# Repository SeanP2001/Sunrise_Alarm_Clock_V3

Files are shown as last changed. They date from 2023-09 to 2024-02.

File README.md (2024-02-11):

# Sunrise Alarm Clock V3

**Table of Contents**

- [Introduction](#introduction)
- [Brief](#brief)
- [Development Roadmap](#development-roadmap)
- [Circuitry](#circuitry)
  - [Schematics](#schematics)
    - [Main PCB](#main-pcb)
    - [Button PCB](#button-pcb)
    - [Light PCB](#light-pcb)
  - [PCB Design](#pcb-design)
    - [Main PCB](#main-pcb-1)
    - [Button PCB](#button-pcb-1)
    - [Light PCB](#light-pcb-1)
  - [Soldering](#soldering)
    - [Main PCB](#main-pcb-2)
    - [Button PCB](#button-pcb-2)
    - [Light PCB](#light-pcb-2)
- [Enclosure](#enclosure)
  - [CAD Enclosure](#cad-enclosure)
  - [Assembled Enclosure](#assembled-enclosure)
- [Code](#code)
  - [Documentation](#documentation)
  - [How to Add a New App](#how-to-add-a-new-app)
- [Further Work](#further-work)

## Introduction

This is the third version of the "Sunrise Alarm Clock" project. [The first version](https://github.com/SeanP2001/Arduino_Sunrise_Alarm_Clock) used an Arduino Mega and an LCD keypad shield. [The second version](https://github.com/SeanP2001/Sunrise_Alarm_Clock_V2) used a Wemos D1 mini (ESP8266) and 0.96" OLED on a single custom PCB. This design was fully functional but it did not look like an alarm clock. I started version 3 with the aim of making the alarm look more premium. 

<div style="display: flex; justify-content: space-between;">
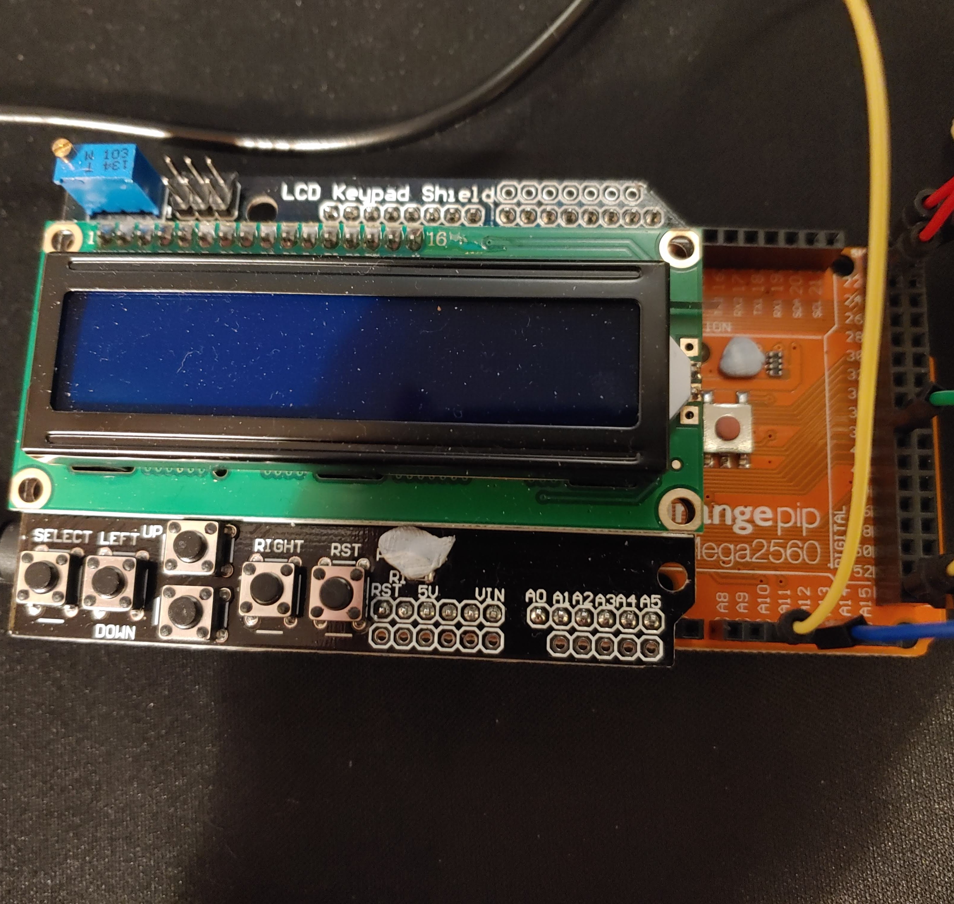
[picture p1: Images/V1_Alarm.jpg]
Alarm V1
    
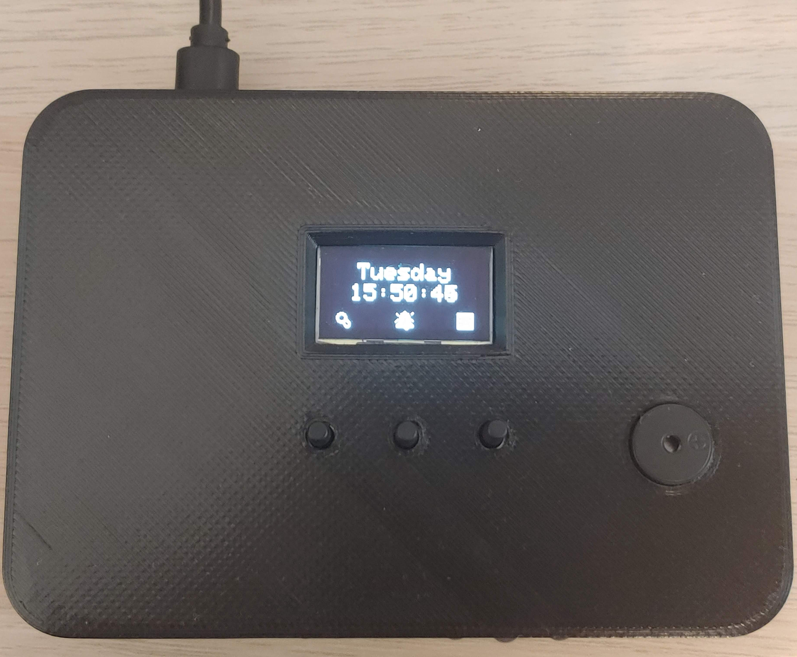
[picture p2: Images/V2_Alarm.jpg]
Alarm V2
    
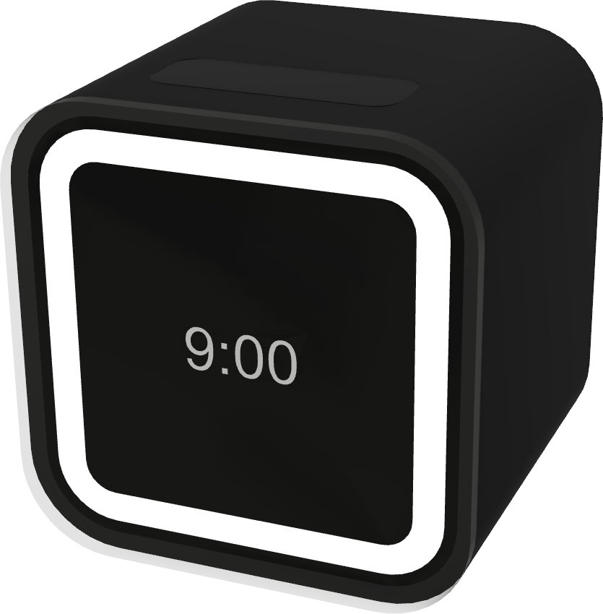
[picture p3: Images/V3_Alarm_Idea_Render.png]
Alarm V3 Concept
    
</div>
<p align="center"><i>Alarm V1, Alarm V2 and Alarm V3 Concept</i></p>

This project was sponsored by PCBWay. To order high-quality, custom PCBs go to [PCBWay.com](https://www.pcbway.com/)

## Brief

The alarm needed to:
- Tell the time
- Use a real-time clock (RTC) to keep the time 
- Use an NTP server to update the time periodically
- Include a larger, 1.5" OLED 
- Include three capacitive touch buttons
- Include two timed USB ports
- Include a bright ringlight on the clock face
- Include a buzzer
- Have a premium feel

## Development Roadmap

The following roadmap outlines the planned milestones for the project. Each step includes testing and documenting.

| **Version** | **Description** |
|---|---|
| V3.1-alpha | Capture Schematic |
| V3.2-alpha | Design Main PCB |
| V3.3-alpha | Design Light PCB |
| V3.4-alpha | Design Button PCB |
| V3.5-alpha | Design and Fabricate Enclosure |
| V3.6-alpha | Solder and Assemble |
| V3.7-alpha | Test Hardware and Document |
| V3.8-alpha | Program Inputs and Outputs |
| V3.9-alpha | Implement App Infrastructure |
| V3.10-alpha | Develop Alarm App |
| V3.11-alpha | Develop Light App |
| V3.12-alpha | Develop USB App |
| V3.13-alpha | Develop Settings App |
| V3.14-alpha | Implement WiFi, NTP Time Sync and Settings Portal |
| V3.0-release  | Initial Release (Document, Test and Fix Bugs) |

## Circuitry

### Schematics

#### Main PCB

<p align="center">
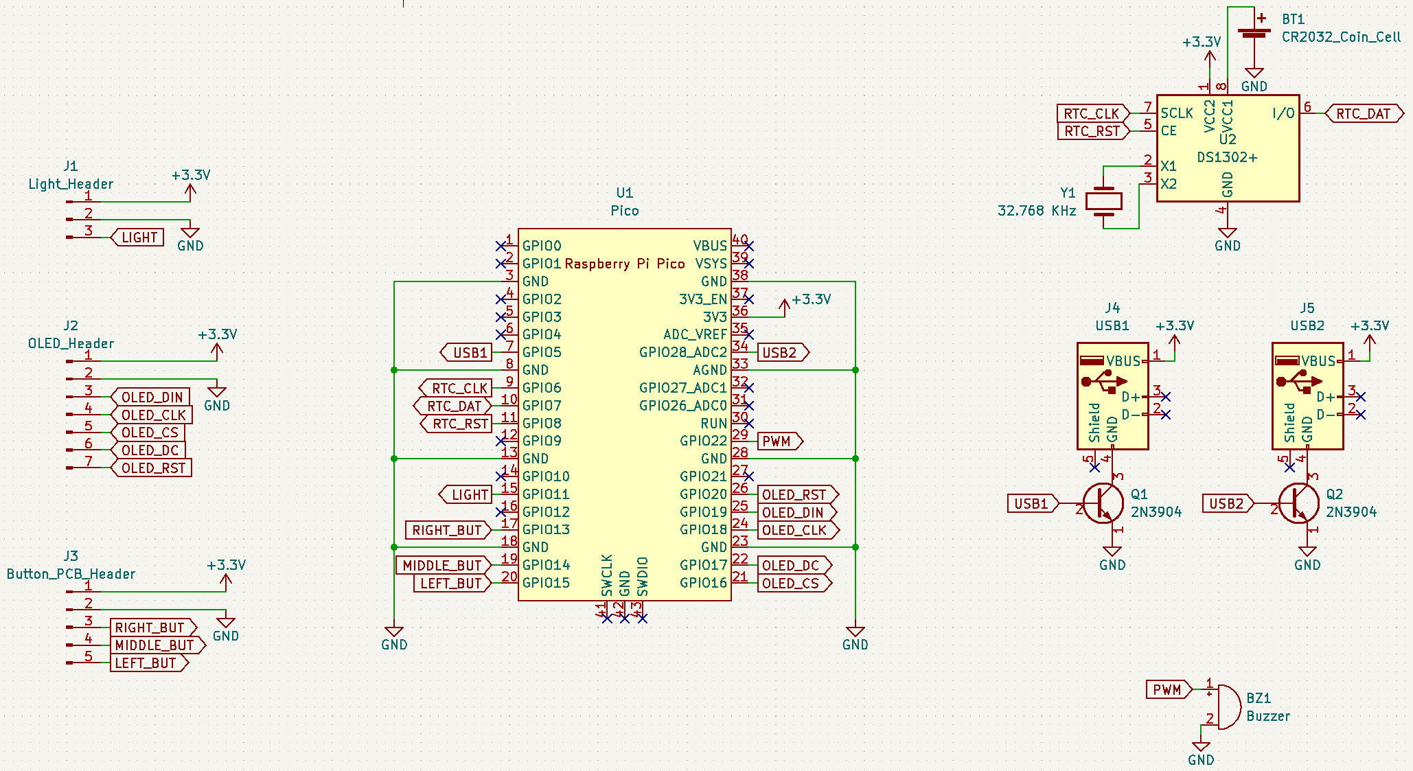
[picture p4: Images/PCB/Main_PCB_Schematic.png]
  
</p>

#### Button PCB

<p align="center">
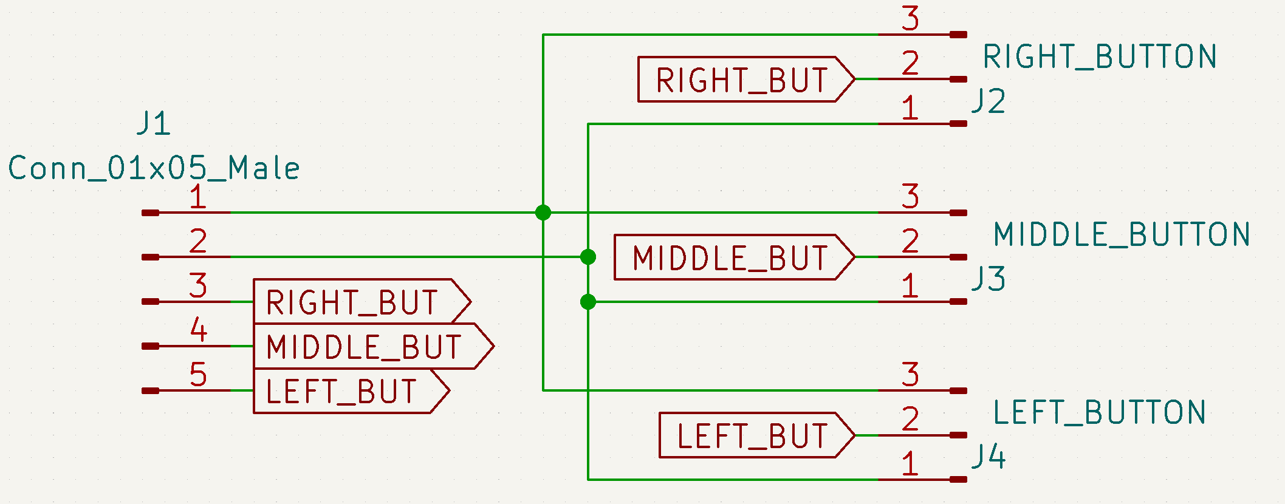
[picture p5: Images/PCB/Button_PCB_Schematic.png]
  
</p>

#### Light PCB

<p align="center">
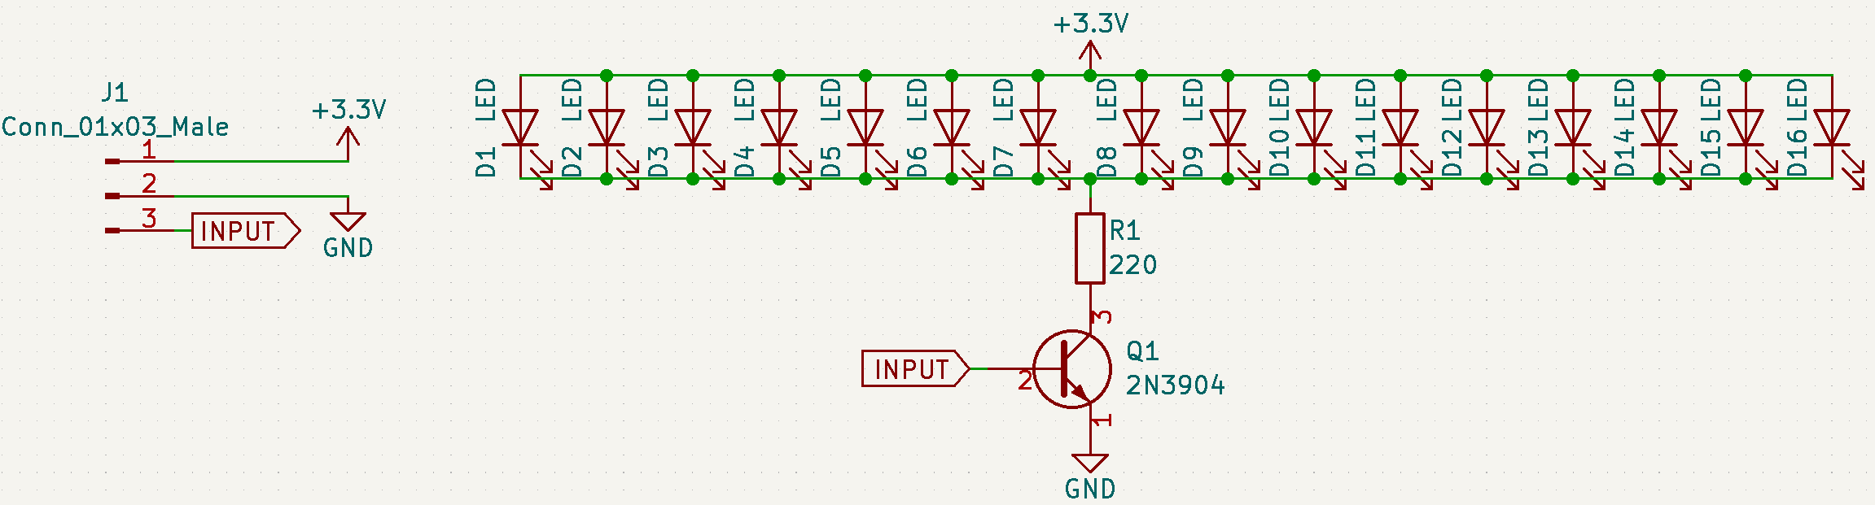
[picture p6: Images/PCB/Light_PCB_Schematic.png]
  
</p>

### PCB Design

#### Main PCB

<div style="display: flex; justify-content: space-between;">
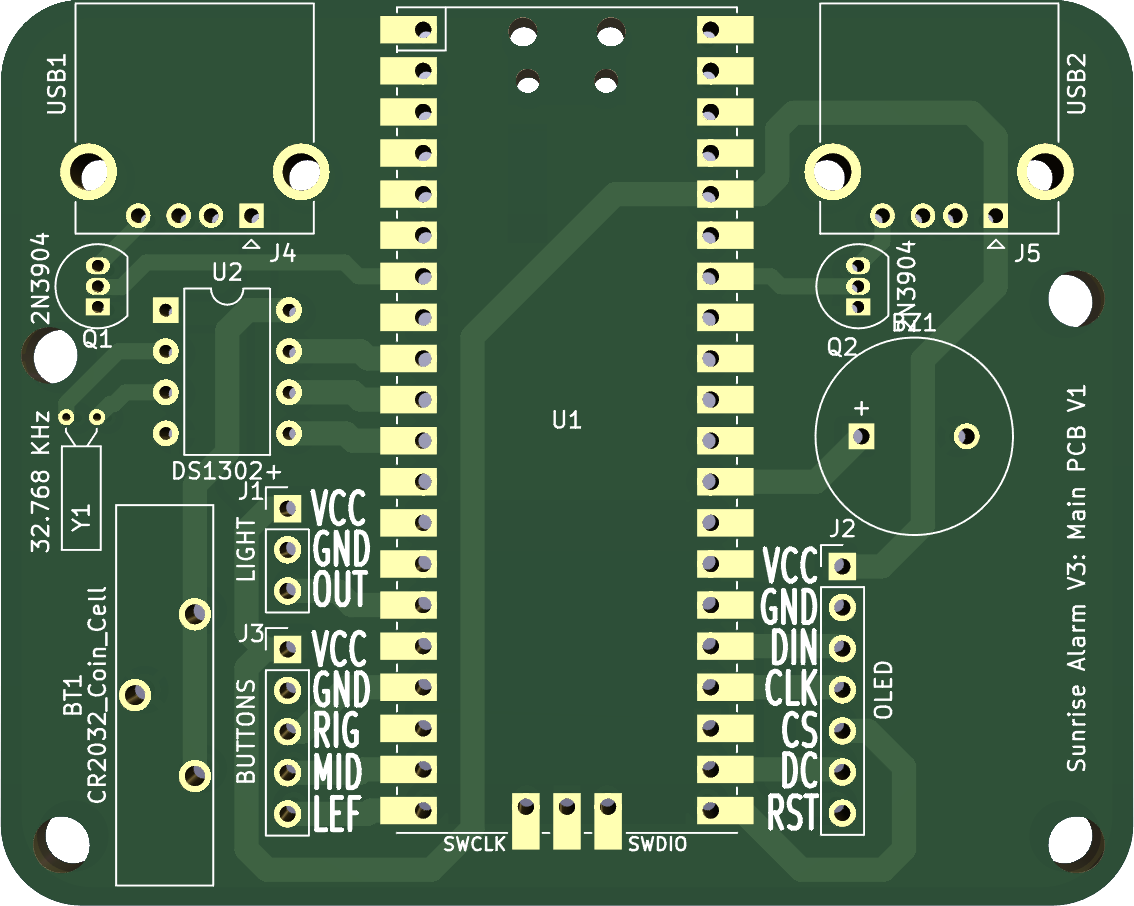
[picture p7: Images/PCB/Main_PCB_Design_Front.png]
Main PCB Front
    
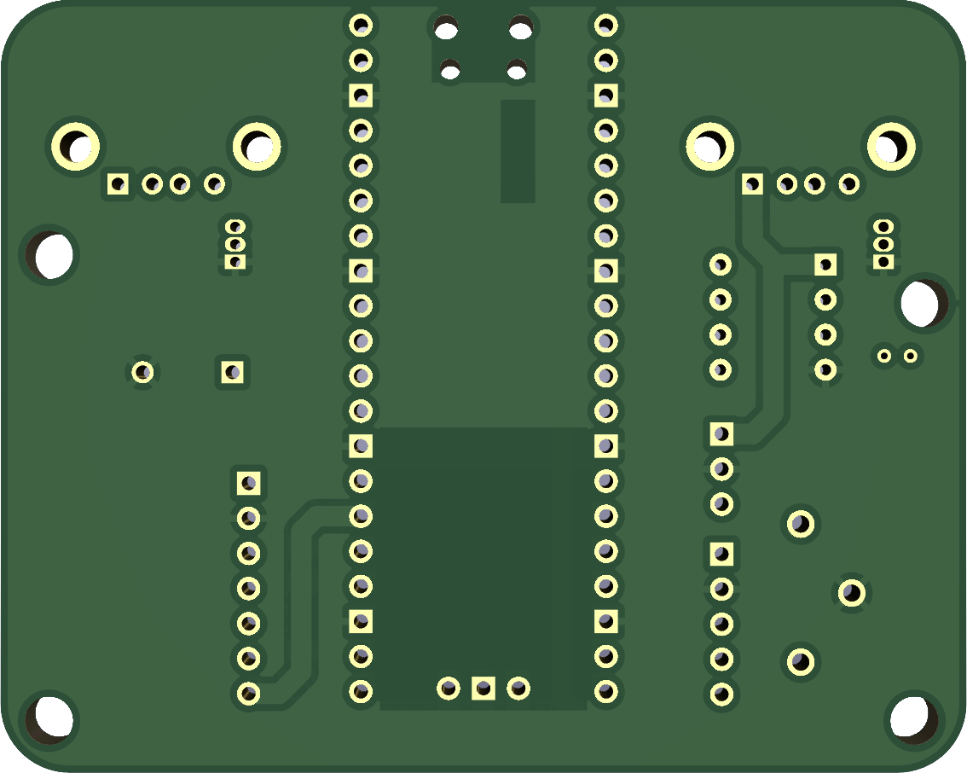
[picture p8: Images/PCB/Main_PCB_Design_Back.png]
Main PCB Back
    
</div>
<p align="center"><i>Main PCB Front and Back</i></p>

#### Button PCB

<div style="display: flex; justify-content: space-between;">
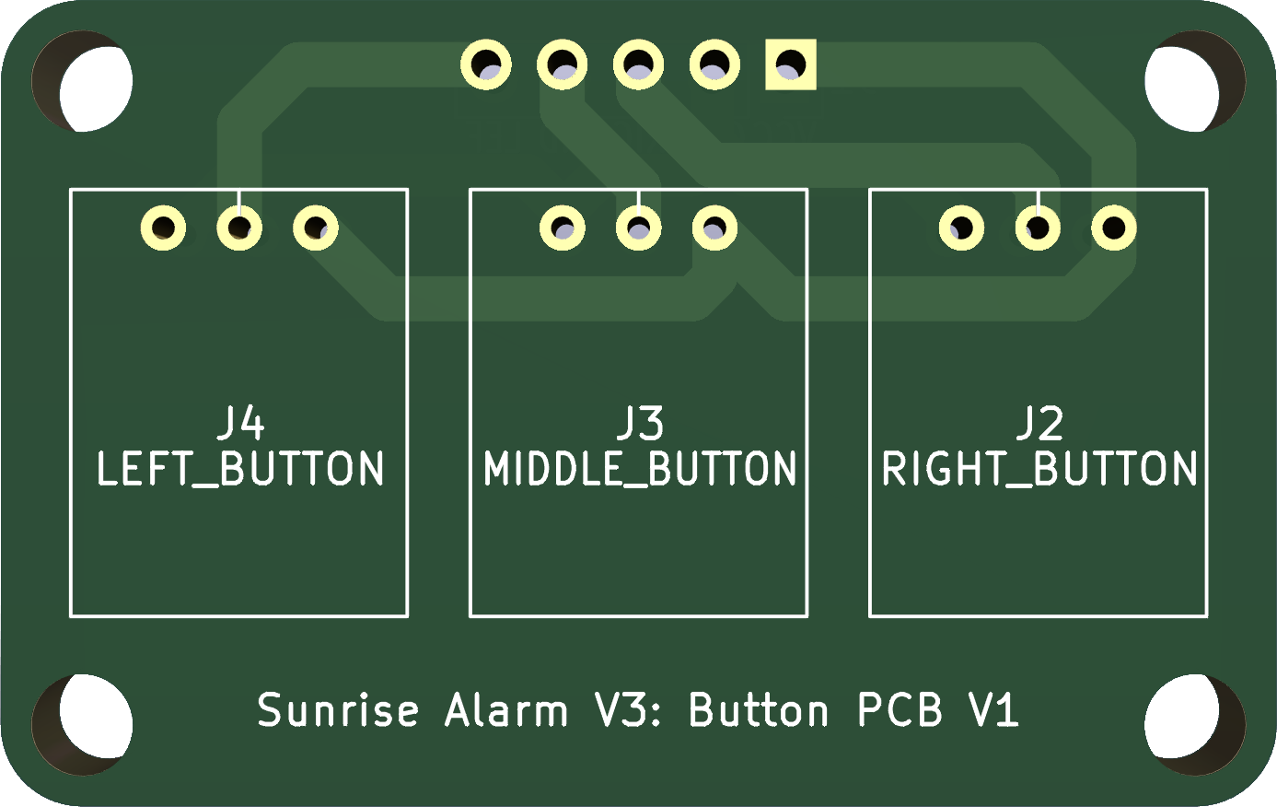
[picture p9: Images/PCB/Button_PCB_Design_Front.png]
Main PCB Front
    
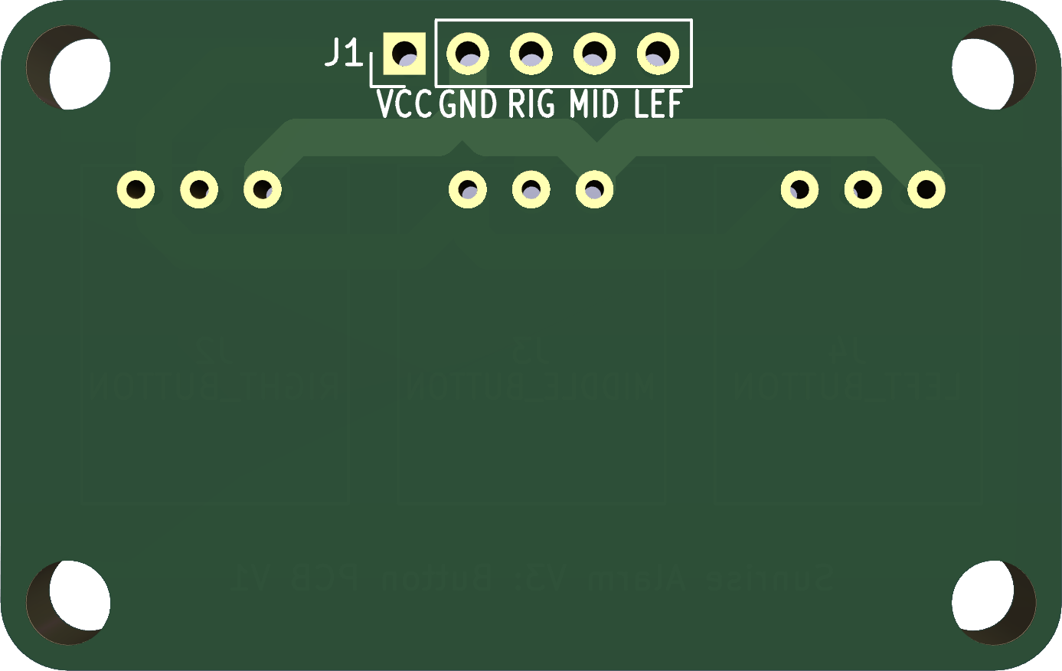
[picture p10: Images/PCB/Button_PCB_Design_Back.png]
Main PCB Back
    
</div>
<p align="center"><i>Button PCB Front and Back</i></p>

#### Light PCB

<div style="display: flex; justify-content: space-between;">
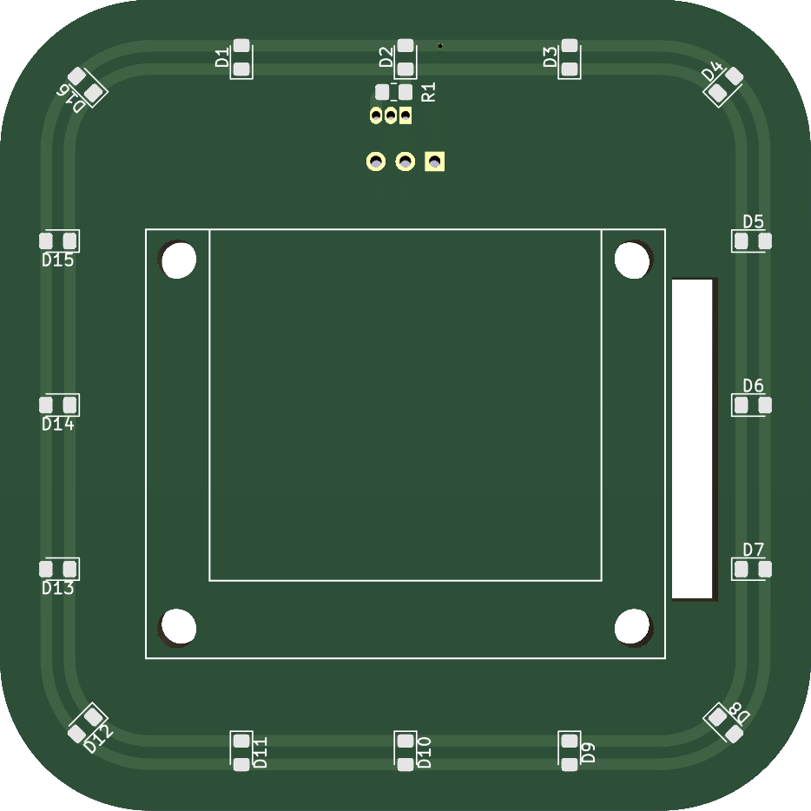
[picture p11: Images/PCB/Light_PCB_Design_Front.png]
Main PCB Front
    
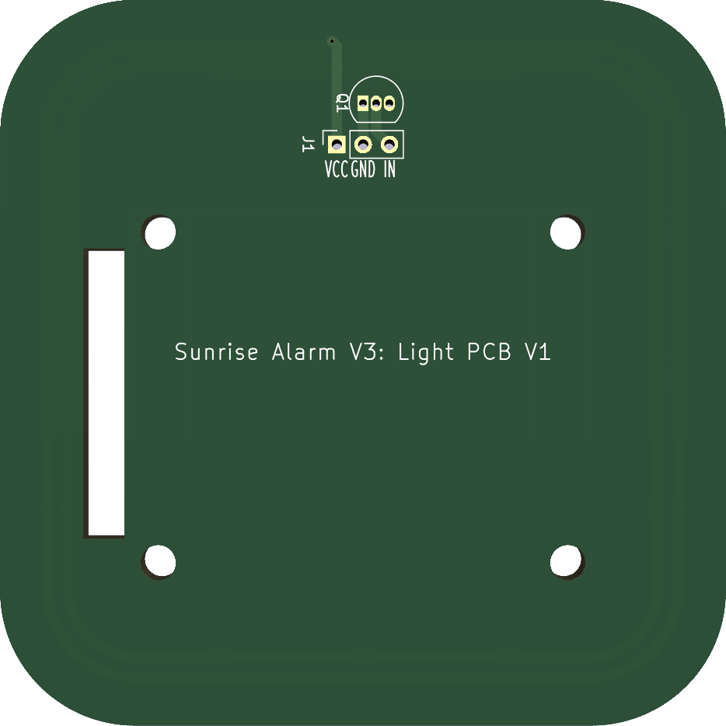
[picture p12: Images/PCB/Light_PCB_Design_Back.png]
Main PCB Back
    
</div>
<p align="center"><i>Light PCB Front and Back</i></p>

### Soldering

I was really impressed by the quality of the PCBs sent by PCBWay. To order high-quality, custom PCBs go to [PCBWay.com](https://www.pcbway.com/). 

#### Main PCB

<div style="display: flex; justify-content: space-between;">
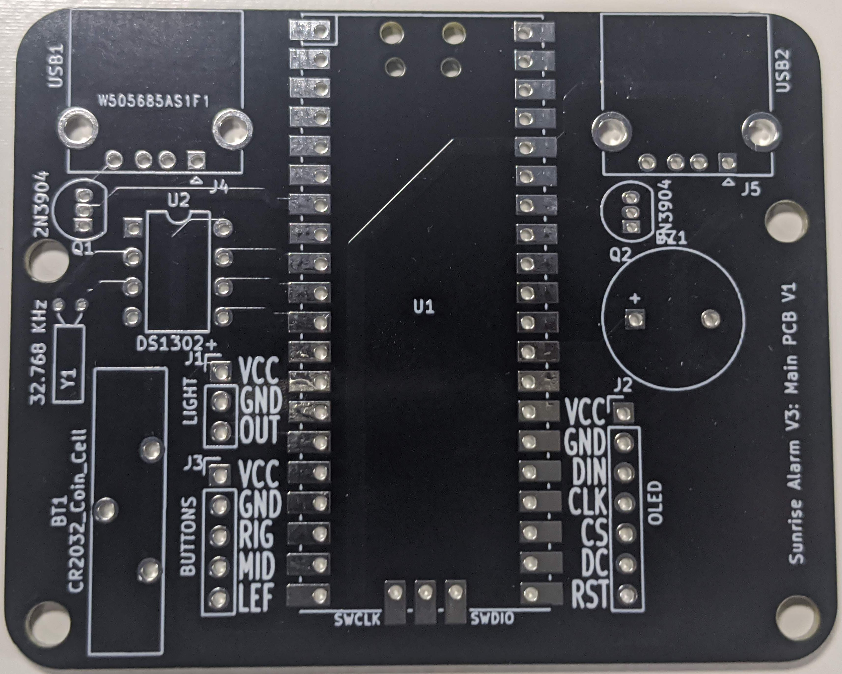
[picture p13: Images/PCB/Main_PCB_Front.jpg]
Main PCB Front
    
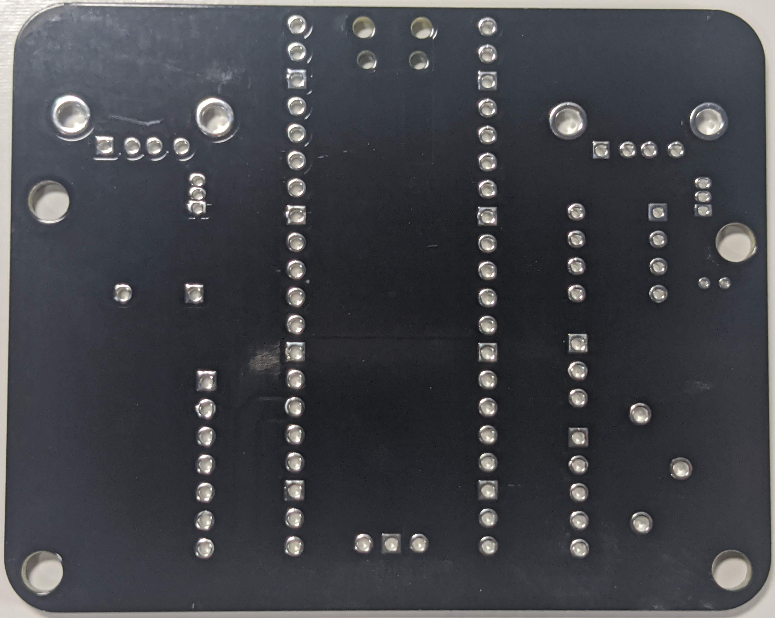
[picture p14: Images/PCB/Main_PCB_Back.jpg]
Main PCB Back
    
</div>
<p align="center"><i>Main PCB Front and Back</i></p>

<p align="center">
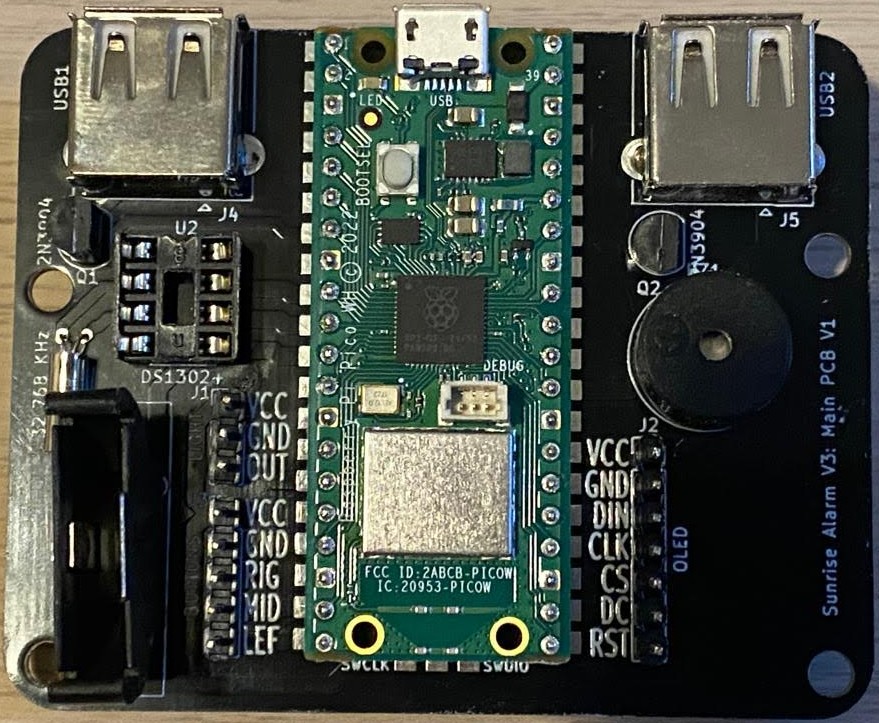
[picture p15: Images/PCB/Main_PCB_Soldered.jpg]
  
</p>
<p align="center"><i>Main PCB Soldered</i></p>

#### Button PCB

<div style="display: flex; justify-content: space-between;">
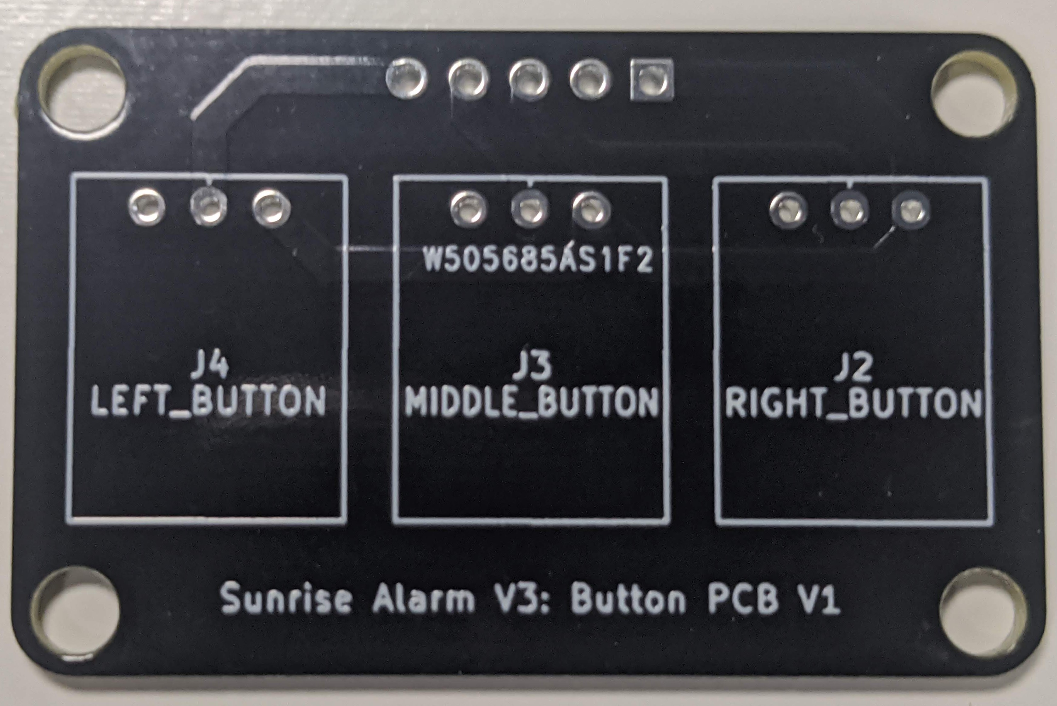
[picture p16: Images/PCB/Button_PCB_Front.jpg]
Main PCB Front
    
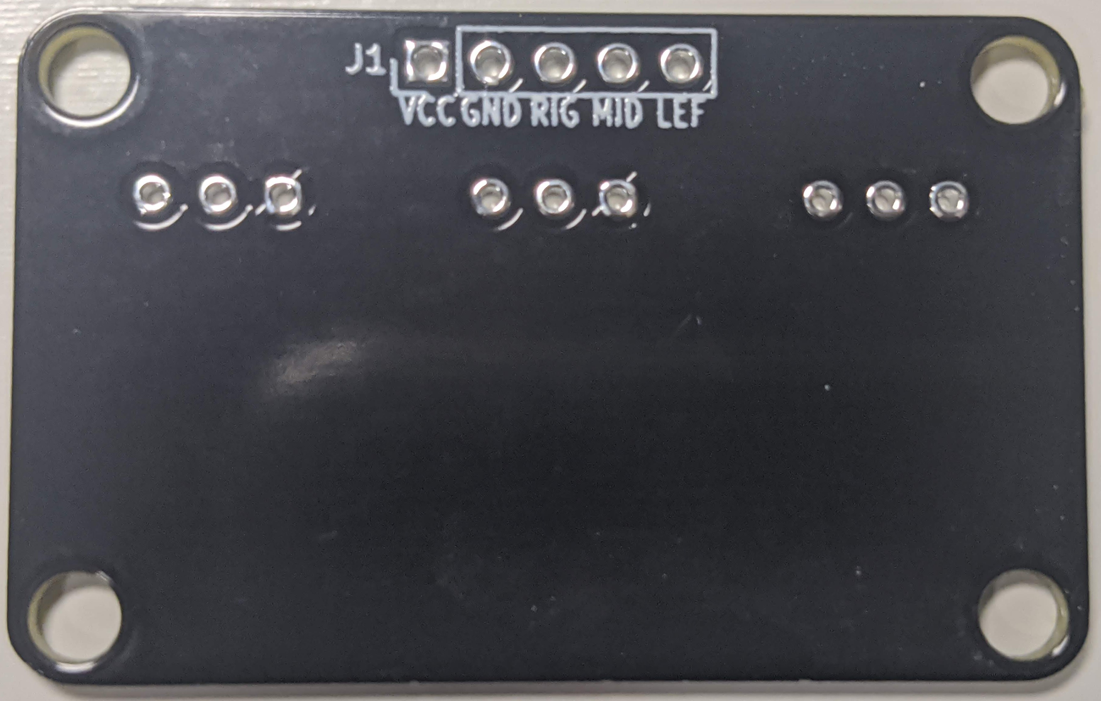
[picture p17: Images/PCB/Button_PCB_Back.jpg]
Main PCB Back
    
</div>
<p align="center"><i>Button PCB Front and Back</i></p>

<p align="center">
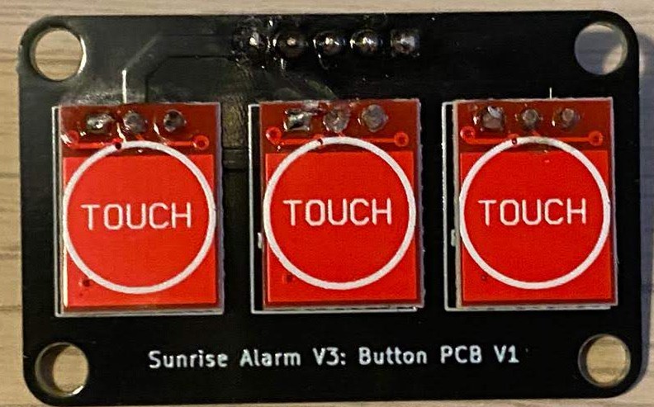
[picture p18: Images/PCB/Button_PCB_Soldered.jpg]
  
</p>
<p align="center"><i>Button PCB Soldered</i></p>

#### Light PCB

<div style="display: flex; justify-content: space-between;">
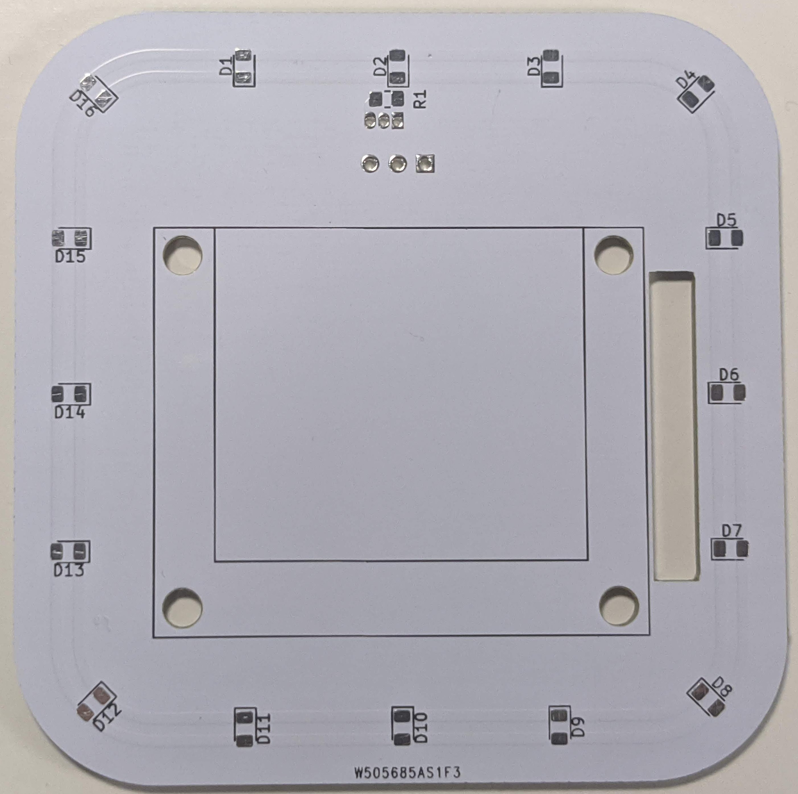
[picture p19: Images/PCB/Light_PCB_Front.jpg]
Main PCB Front
    
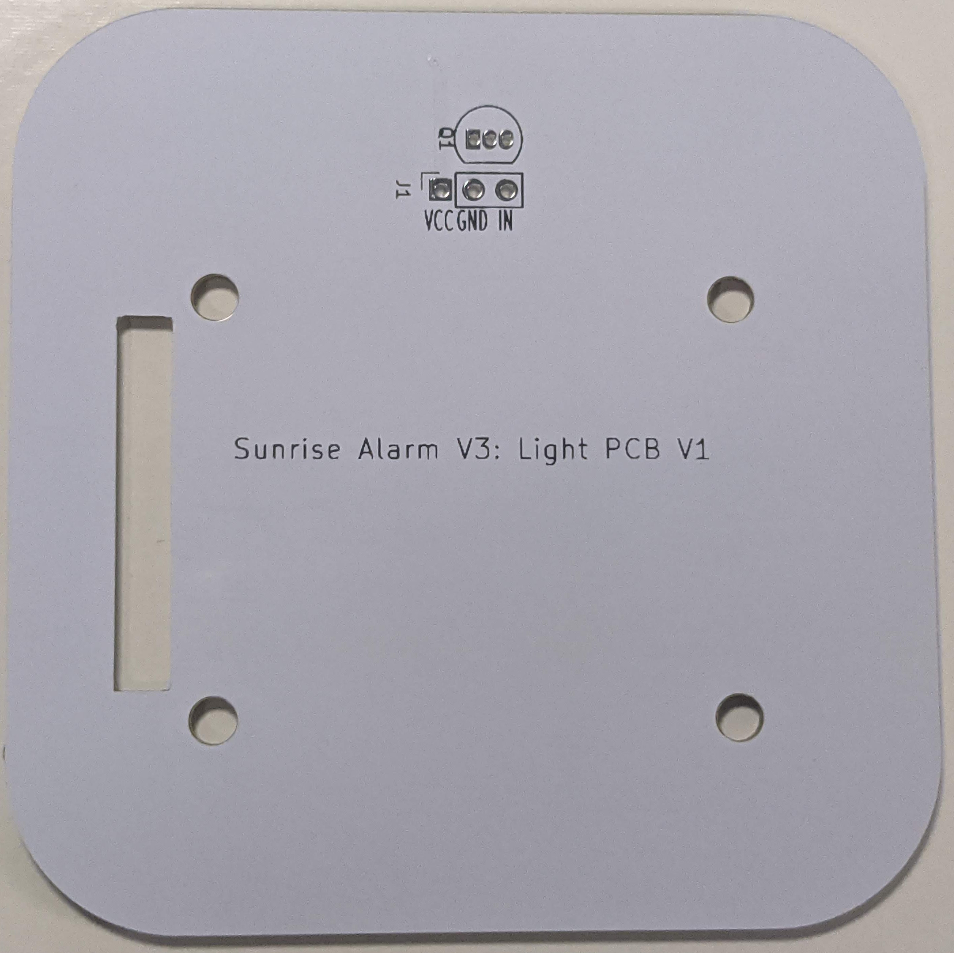
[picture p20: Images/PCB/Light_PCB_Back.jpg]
Main PCB Back
    
</div>
<p align="center"><i>Light PCB Front and Back</i></p>

<p align="center">
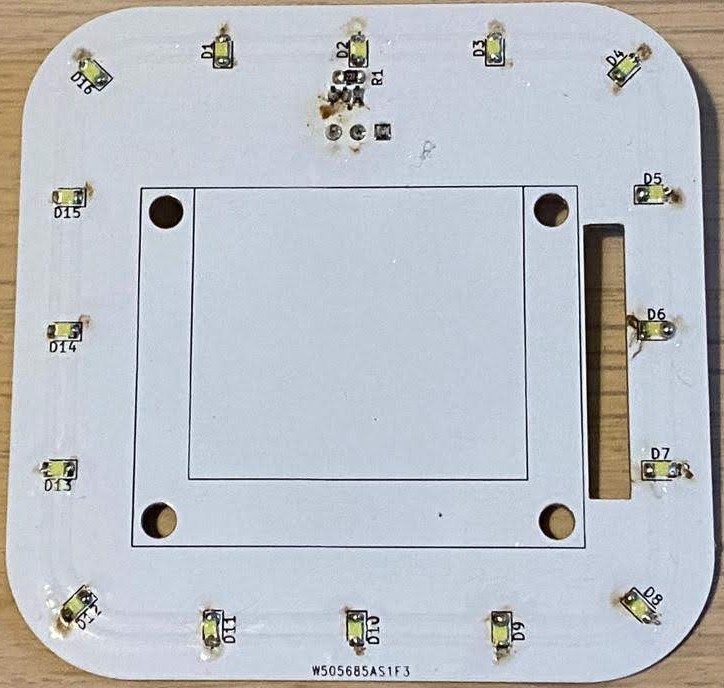
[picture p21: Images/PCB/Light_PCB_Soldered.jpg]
  
</p>
<p align="center"><i>Light PCB Soldered</i></p>

## Enclosure

### CAD Enclosure

<div style="display: flex; justify-content: space-between;">
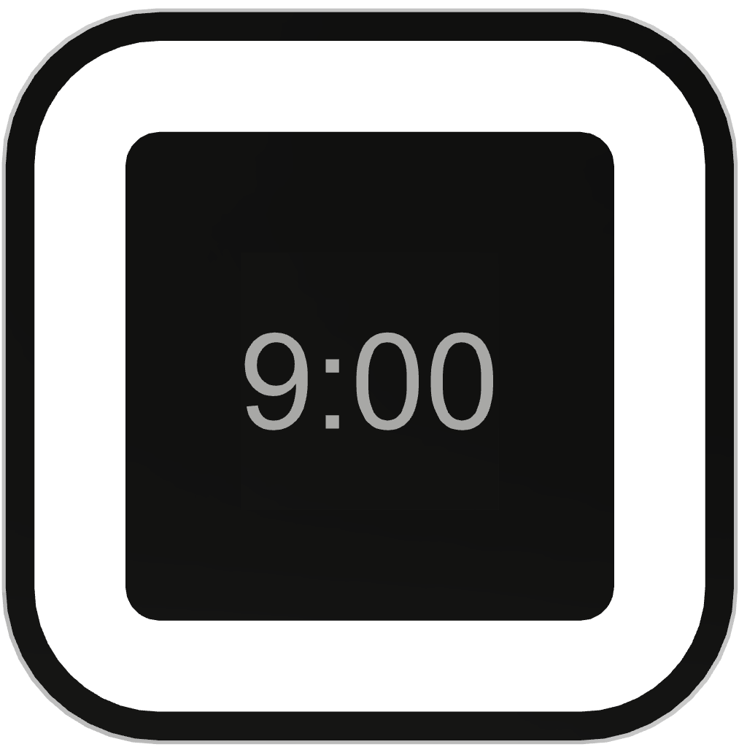
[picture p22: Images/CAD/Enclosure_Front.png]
Alarm Enclosure Front
    
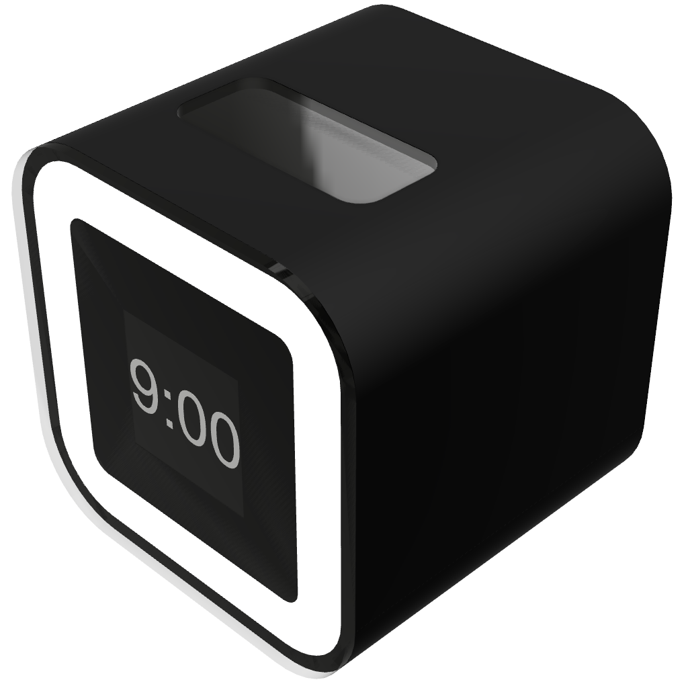
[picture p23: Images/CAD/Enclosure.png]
Alarm Enclosure
    
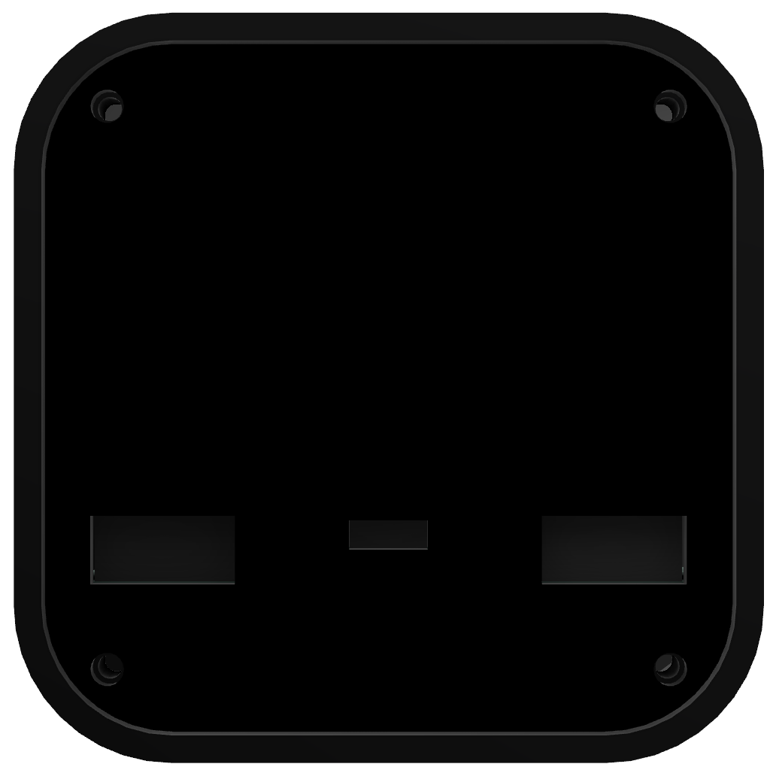
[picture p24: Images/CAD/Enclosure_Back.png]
Alarm Enclosure Back
    
</div>
<div style="display: flex; justify-content: space-between; margin-top: 10px;">
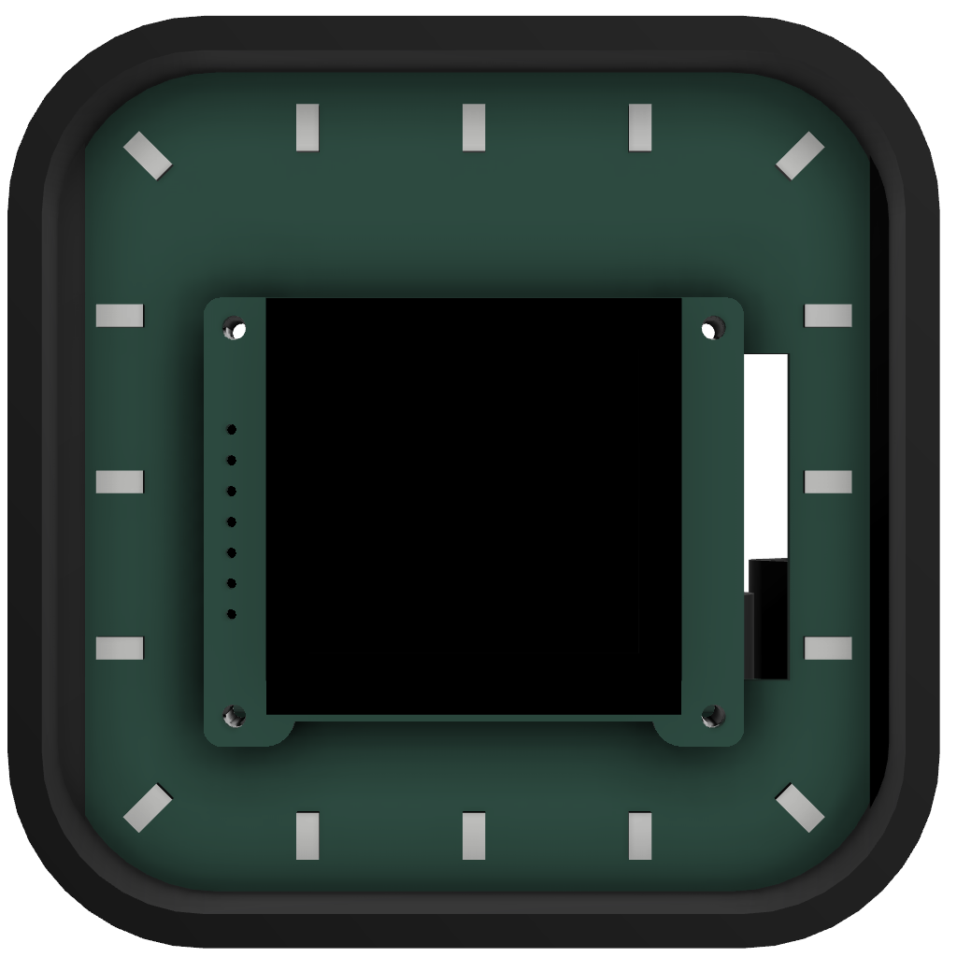
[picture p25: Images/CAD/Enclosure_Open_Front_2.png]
Alarm Enclosure Open Front
    
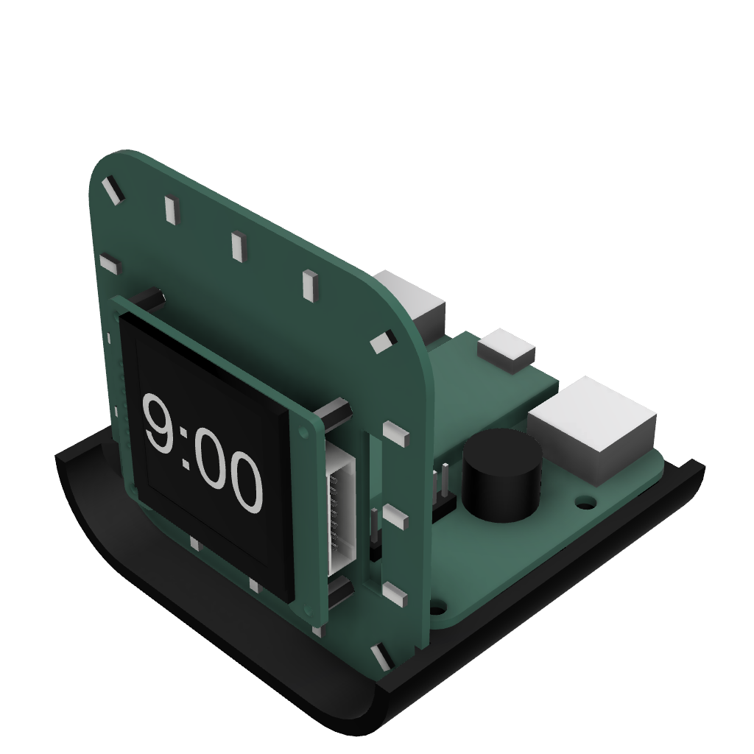
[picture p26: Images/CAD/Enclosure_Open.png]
Alarm Enclosure Open
    
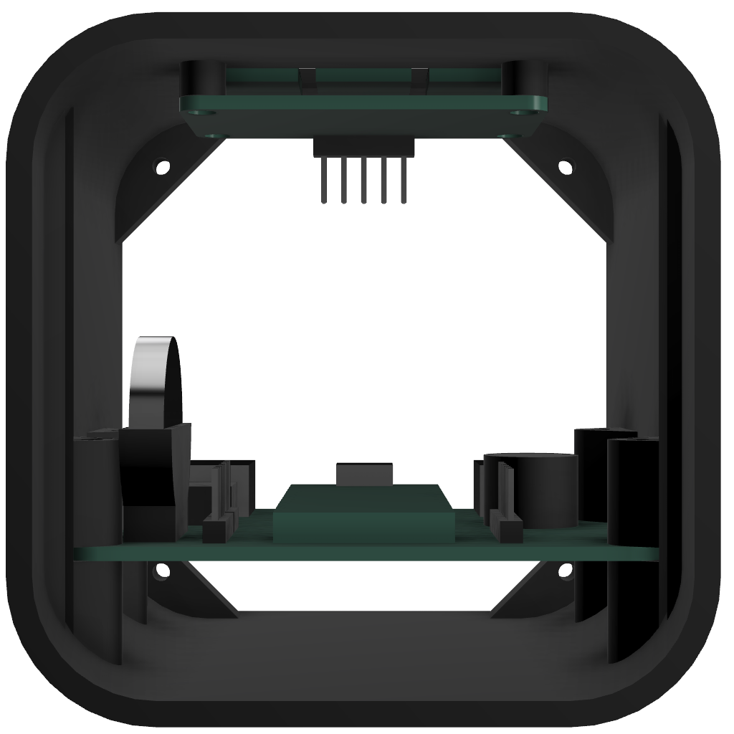
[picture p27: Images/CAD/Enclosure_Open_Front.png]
Alarm Enclosure Open Front
    
</div>

### Assembled Enclosure

<div style="display: flex; justify-content: center;">
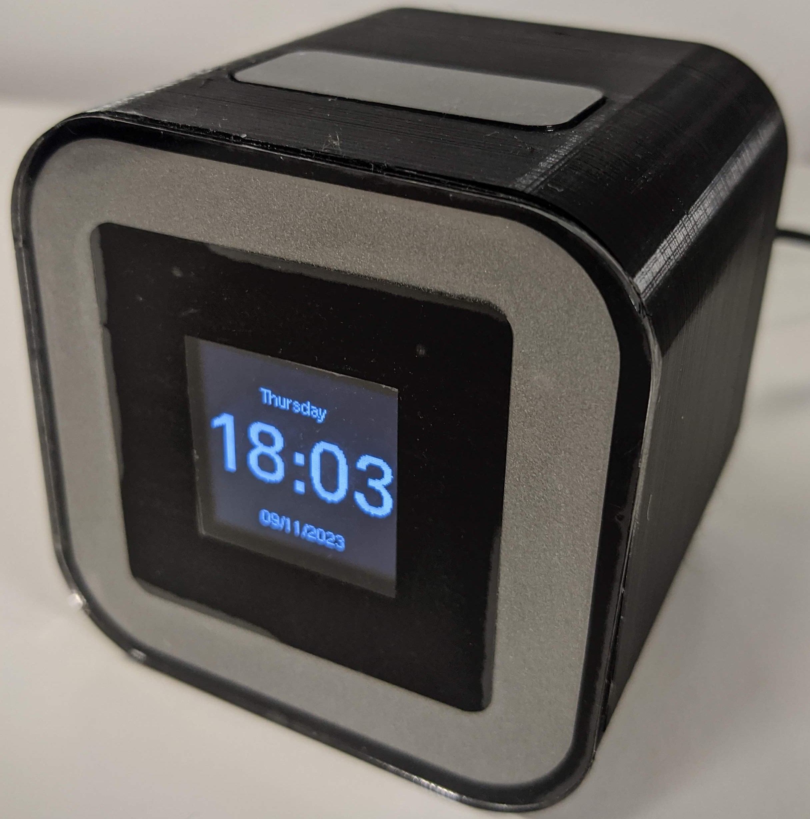
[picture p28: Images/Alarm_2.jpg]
    
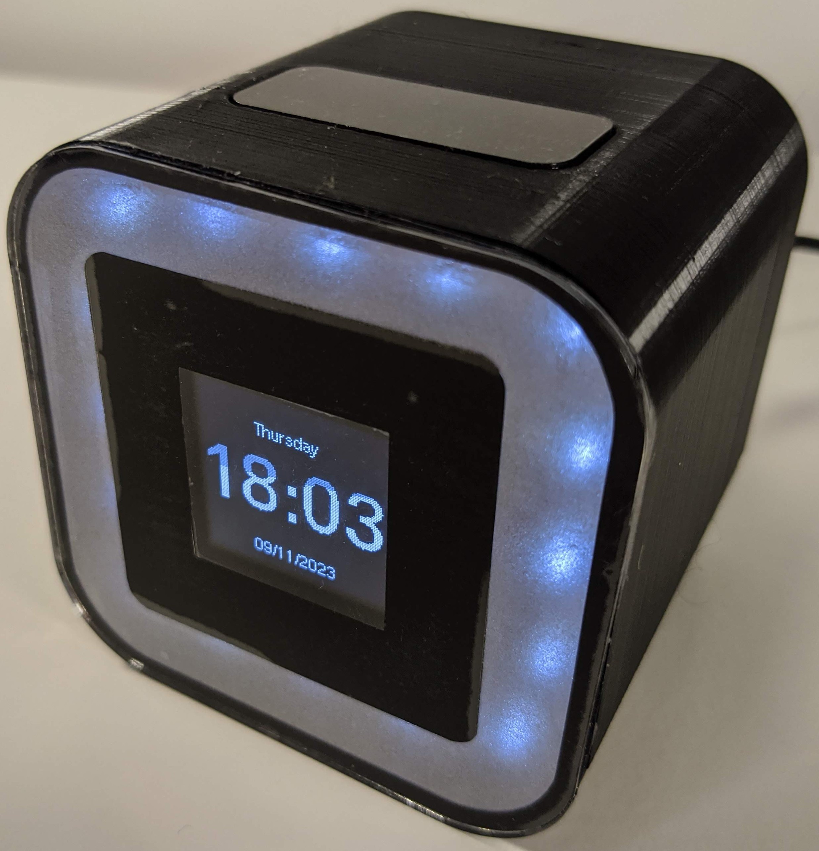
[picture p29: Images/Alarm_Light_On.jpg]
    
</div>
<div style="display: flex; justify-content: center;">
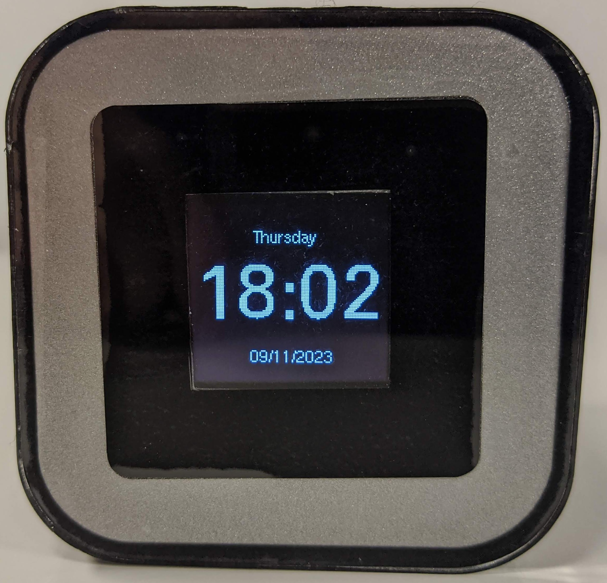
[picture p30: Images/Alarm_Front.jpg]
Alarm V1
    
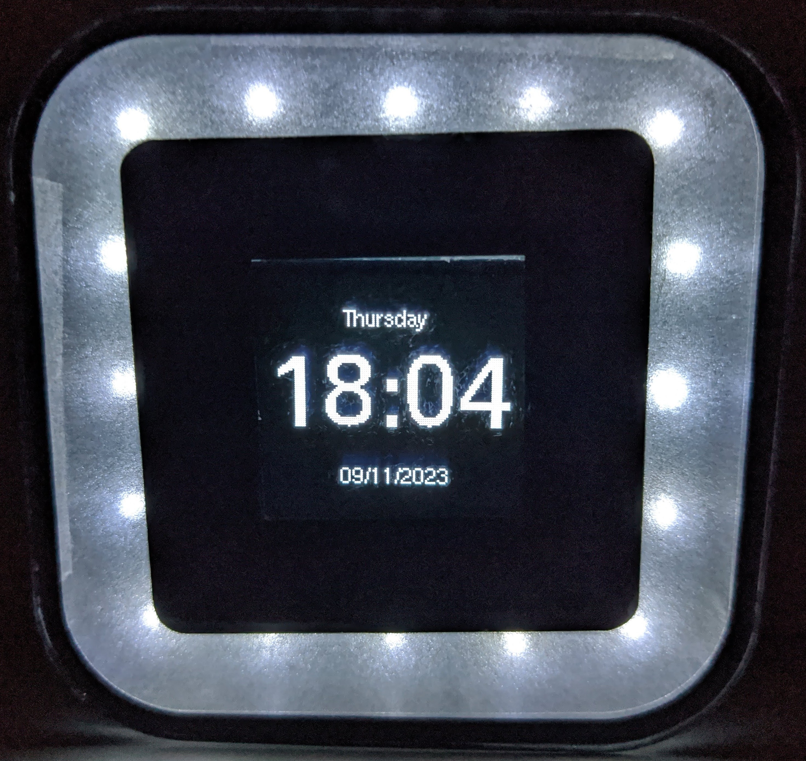
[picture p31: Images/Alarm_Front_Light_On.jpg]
Alarm V2
    
</div>

## Code

### Documentation

View the Doxygen documentation for this project [here](https://raw.githack.com/SeanP2001/Sunrise_Alarm_Clock_V3/main/Code/Documentation/html/index.html).

### How to Add a New App

1. Copy the `TemplateApp.h` and `TemplateApp.cpp` files, changing their names to reflect your app.  
2. Change the header guards, file headers and and include statements to the new file names.  
3. Do a find and replace for the phrase "TemplateApp" replacing it with the name of your app (both files).  
4. Add code to each of the functions.  
5. Include the header file in the main program.  
6. Instantiate the new `____App` object.  
7. Increment the `noOfApps` variable.  
8. Add a reference to the new app object at the next index of the `apps` array. e.g.`apps[i] = &____App;`.

## Further Work

In future I would like to;
- Change the design to not use vinyl as it is difficult to get a perfect result using it.
- Add software functions:
  - Wake up games
  - Daily weather forecast
  - Daily calendar events
  - Log sleep and wake times
  - Mood tracker
  - Habit tracker

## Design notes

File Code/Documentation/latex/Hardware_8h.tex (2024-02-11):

\hypertarget{Hardware_8h}{}\doxysection{Hardware.\+h File Reference}
\label{Hardware_8h}\index{Hardware.h@{Hardware.h}}

Defines the \mbox{\hyperlink{structHardware}{Hardware}} struct.  

{\ttfamily \#include $<$Arduino.\+h$>$}\newline
{\ttfamily \#include $<$SPI.\+h$>$}\newline
{\ttfamily \#include $<$Ds1302.\+h$>$}\newline
{\ttfamily \#include $<$U8g2lib.\+h$>$}\newline
{\ttfamily \#include \char`\"{}Device.\+h\char`\"{}}\newline
{\ttfamily \#include \char`\"{}PWMDevice.\+h\char`\"{}}\newline
{\ttfamily \#include \char`\"{}Buzzer.\+h\char`\"{}}\newline
Include dependency graph for Hardware.\+h\+:\nopagebreak
\begin{figure}[H]
\begin{center}
\leavevmode
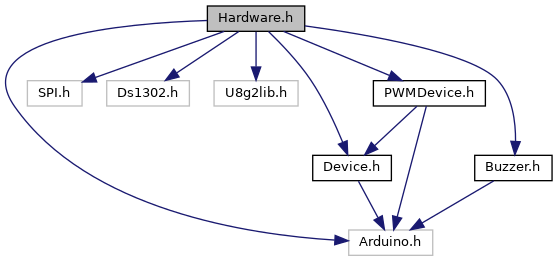
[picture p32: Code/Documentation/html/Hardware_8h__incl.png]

\end{center}
\end{figure}
This graph shows which files directly or indirectly include this file\+:
\nopagebreak
\begin{figure}[H]
\begin{center}
\leavevmode
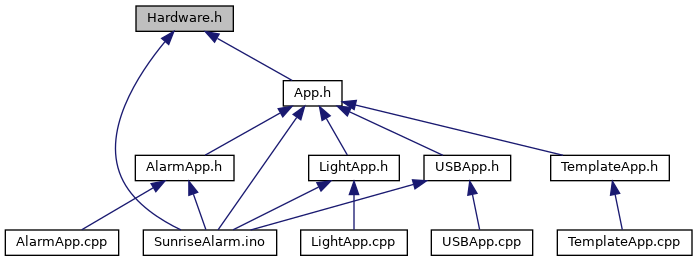
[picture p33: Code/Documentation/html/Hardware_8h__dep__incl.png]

\end{center}
\end{figure}
\doxysubsection*{Classes}
\begin{DoxyCompactItemize}
\item 
struct \mbox{\hyperlink{structHardware}{Hardware}}
\begin{DoxyCompactList}\small\item\em Represents the hardware components used in the project. \end{DoxyCompactList}\end{DoxyCompactItemize}

\doxysubsection{Detailed Description}
Defines the \mbox{\hyperlink{structHardware}{Hardware}} struct. 

\begin{DoxyAuthor}{Author}
Sean Price 
\end{DoxyAuthor}
\begin{DoxyVersion}{Version}
0.\+1 
\end{DoxyVersion}
\begin{DoxyDate}{Date}
13/01/2024 
\end{DoxyDate}

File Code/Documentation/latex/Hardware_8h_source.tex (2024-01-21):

\hypertarget{Hardware_8h_source}{}\doxysection{Hardware.\+h}
\mbox{\hyperlink{Hardware_8h}{Go to the documentation of this file.}}
\begin{DoxyCode}{0}
\DoxyCodeLine{1 }
\DoxyCodeLine{11 \textcolor{preprocessor}{\#ifndef HARDWARE\_H}}
\DoxyCodeLine{12 \textcolor{preprocessor}{\#define HARDWARE\_H}}
\DoxyCodeLine{13 }
\DoxyCodeLine{14 \textcolor{preprocessor}{\#include <Arduino.h>}}
\DoxyCodeLine{15 }
\DoxyCodeLine{16 \textcolor{preprocessor}{\#include <SPI.h>}}
\DoxyCodeLine{17 \textcolor{preprocessor}{\#include <Ds1302.h>}}
\DoxyCodeLine{18 \textcolor{preprocessor}{\#include <U8g2lib.h>}}
\DoxyCodeLine{19 }
\DoxyCodeLine{20 \textcolor{preprocessor}{\#include "{}\mbox{\hyperlink{Device_8h}{Device.h}}"{}}}
\DoxyCodeLine{21 \textcolor{preprocessor}{\#include "{}\mbox{\hyperlink{PWMDevice_8h}{PWMDevice.h}}"{}}}
\DoxyCodeLine{22 \textcolor{preprocessor}{\#include "{}\mbox{\hyperlink{Buzzer_8h}{Buzzer.h}}"{}}}
\DoxyCodeLine{23 }
\DoxyCodeLine{30 \textcolor{keyword}{struct }\mbox{\hyperlink{structHardware}{Hardware}}}
\DoxyCodeLine{31 \{}
\DoxyCodeLine{32   U8G2\_SSD1327\_WS\_128X128\_F\_4W\_SW\_SPI \&\mbox{\hyperlink{structHardware_a44c7b0624c82b47fef0c11aeef2f4ac0}{display}}; }
\DoxyCodeLine{33   Ds1302 \&\mbox{\hyperlink{structHardware_aa6ac7f524135439703fad83fa634af4d}{rtc}};                                  }
\DoxyCodeLine{34   \mbox{\hyperlink{classPWMDevice}{PWMDevice}} \&\mbox{\hyperlink{structHardware_ad6bcffa2848d3050c951477079b4f595}{light}};                             }
\DoxyCodeLine{35   \mbox{\hyperlink{classDevice}{Device}} \&\mbox{\hyperlink{structHardware_a4025251ad5b50af22c68ae7217dcfe26}{usb1}};                                 }
\DoxyCodeLine{36   \mbox{\hyperlink{classDevice}{Device}} \&\mbox{\hyperlink{structHardware_a05b80e737fe377ffa0e8695217a9dbd9}{usb2}};                                 }
\DoxyCodeLine{37   \mbox{\hyperlink{classBuzzer}{Buzzer}} \&\mbox{\hyperlink{structHardware_a37be241ef1d34177749769073f88a6cd}{buzzer}};                               }
\DoxyCodeLine{38 \};}
\DoxyCodeLine{39 }
\DoxyCodeLine{40 \textcolor{preprocessor}{\#endif }\textcolor{comment}{// HARDWARE\_H}}

\end{DoxyCode}

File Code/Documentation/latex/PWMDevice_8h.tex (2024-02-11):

\hypertarget{PWMDevice_8h}{}\doxysection{PWMDevice.\+h File Reference}
\label{PWMDevice_8h}\index{PWMDevice.h@{PWMDevice.h}}

Defines the \mbox{\hyperlink{classPWMDevice}{PWMDevice}} class, a subclass of the \mbox{\hyperlink{classDevice}{Device}} class.  

{\ttfamily \#include $<$Arduino.\+h$>$}\newline
{\ttfamily \#include \char`\"{}Device.\+h\char`\"{}}\newline
Include dependency graph for PWMDevice.\+h\+:\nopagebreak
\begin{figure}[H]
\begin{center}
\leavevmode
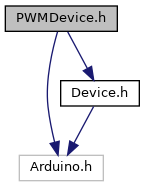
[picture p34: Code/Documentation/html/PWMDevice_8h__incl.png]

\end{center}
\end{figure}
This graph shows which files directly or indirectly include this file\+:
\nopagebreak
\begin{figure}[H]
\begin{center}
\leavevmode
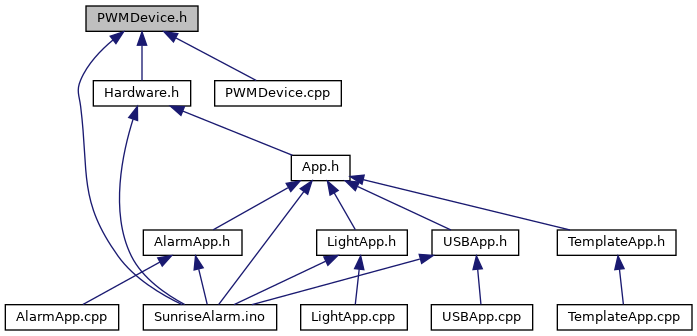
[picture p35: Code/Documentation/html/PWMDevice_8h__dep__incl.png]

\end{center}
\end{figure}
\doxysubsection*{Classes}
\begin{DoxyCompactItemize}
\item 
class \mbox{\hyperlink{classPWMDevice}{PWMDevice}}
\begin{DoxyCompactList}\small\item\em A class representing a PWM output device connected to a pin on the microcontroller. \end{DoxyCompactList}\end{DoxyCompactItemize}

\doxysubsection{Detailed Description}
Defines the \mbox{\hyperlink{classPWMDevice}{PWMDevice}} class, a subclass of the \mbox{\hyperlink{classDevice}{Device}} class. 

\begin{DoxyAuthor}{Author}
Sean Price 
\end{DoxyAuthor}
\begin{DoxyVersion}{Version}
0.\+1 
\end{DoxyVersion}
\begin{DoxyDate}{Date}
13/01/2024 
\end{DoxyDate}

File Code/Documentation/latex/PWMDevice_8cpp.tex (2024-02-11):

\hypertarget{PWMDevice_8cpp}{}\doxysection{PWMDevice.\+cpp File Reference}
\label{PWMDevice_8cpp}\index{PWMDevice.cpp@{PWMDevice.cpp}}

Implements the \mbox{\hyperlink{classPWMDevice}{PWMDevice}} class.  

{\ttfamily \#include \char`\"{}PWMDevice.\+h\char`\"{}}\newline
Include dependency graph for PWMDevice.\+cpp\+:\nopagebreak
\begin{figure}[H]
\begin{center}
\leavevmode
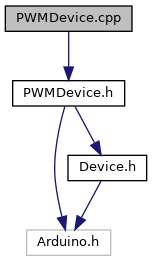
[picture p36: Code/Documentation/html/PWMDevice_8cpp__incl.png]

\end{center}
\end{figure}

\doxysubsection{Detailed Description}
Implements the \mbox{\hyperlink{classPWMDevice}{PWMDevice}} class. 

\begin{DoxyAuthor}{Author}
Sean Price 
\end{DoxyAuthor}
\begin{DoxyVersion}{Version}
0.\+1 
\end{DoxyVersion}
\begin{DoxyDate}{Date}
13/01/2024 
\end{DoxyDate}

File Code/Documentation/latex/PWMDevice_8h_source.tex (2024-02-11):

\hypertarget{PWMDevice_8h_source}{}\doxysection{PWMDevice.\+h}
\mbox{\hyperlink{PWMDevice_8h}{Go to the documentation of this file.}}
\begin{DoxyCode}{0}
\DoxyCodeLine{1 }
\DoxyCodeLine{11 \textcolor{preprocessor}{\#ifndef PWM\_DEVICE\_H}}
\DoxyCodeLine{12 \textcolor{preprocessor}{\#define PWM\_DEVICE\_H}}
\DoxyCodeLine{13 }
\DoxyCodeLine{14 \textcolor{preprocessor}{\#include <Arduino.h>}}
\DoxyCodeLine{15 \textcolor{preprocessor}{\#include "{}\mbox{\hyperlink{Device_8h}{Device.h}}"{}}}
\DoxyCodeLine{16 }
\DoxyCodeLine{25 \textcolor{keyword}{class }\mbox{\hyperlink{classPWMDevice}{PWMDevice}} : \textcolor{keyword}{public} \mbox{\hyperlink{classDevice}{Device}} \{}
\DoxyCodeLine{26 \textcolor{keyword}{private}:}
\DoxyCodeLine{27   uint8\_t pinNo;     }
\DoxyCodeLine{28   uint8\_t level;     }
\DoxyCodeLine{29   uint8\_t maxLevel;  }
\DoxyCodeLine{30 }
\DoxyCodeLine{31   \textcolor{keyword}{const} \textcolor{keyword}{static} uint8\_t DEFAULT\_MAX\_LEVEL;  }
\DoxyCodeLine{32   \textcolor{keyword}{const} \textcolor{keyword}{static} uint8\_t DEFAULT\_LEVEL;      }
\DoxyCodeLine{33   \textcolor{keyword}{const} \textcolor{keyword}{static} uint8\_t MIN\_VAL;            }
\DoxyCodeLine{34   \textcolor{keyword}{const} \textcolor{keyword}{static} uint8\_t MAX\_VAL;            }
\DoxyCodeLine{35 }
\DoxyCodeLine{36 \textcolor{keyword}{public}:}
\DoxyCodeLine{42   \mbox{\hyperlink{classPWMDevice_afe34260d1fe31022be93e07a8850201e}{PWMDevice}}(uint8\_t pinNo);}
\DoxyCodeLine{43 }
\DoxyCodeLine{44 }
\DoxyCodeLine{51   \mbox{\hyperlink{classPWMDevice_afe34260d1fe31022be93e07a8850201e}{PWMDevice}}(uint8\_t pinNo, uint8\_t maxLevel);}
\DoxyCodeLine{52 }
\DoxyCodeLine{53 }
\DoxyCodeLine{58   \textcolor{keywordtype}{void} \mbox{\hyperlink{classPWMDevice_a80a1acf9fc40e45b9247184a3d965f74}{turnOn}}() \textcolor{keyword}{override};}
\DoxyCodeLine{59 }
\DoxyCodeLine{60 }
\DoxyCodeLine{66   \textcolor{keywordtype}{void} \mbox{\hyperlink{classPWMDevice_a8e76e753f0b0669ba28de2e0514f413f}{turnOnFull}}();}
\DoxyCodeLine{67 }
\DoxyCodeLine{68 }
\DoxyCodeLine{73   \textcolor{keywordtype}{void} \mbox{\hyperlink{classPWMDevice_ab824d7b345d44581a28d7a117cafdbcd}{increaseLevel}}();}
\DoxyCodeLine{74 }
\DoxyCodeLine{75 }
\DoxyCodeLine{80   \textcolor{keywordtype}{void} \mbox{\hyperlink{classPWMDevice_a659a470f84d7c07177eae101783f7d7a}{decreaseLevel}}();}
\DoxyCodeLine{81 }
\DoxyCodeLine{82 }
\DoxyCodeLine{88   uint8\_t \mbox{\hyperlink{classPWMDevice_a532992c1296e3794541a660d729266a7}{getLevel}}();}
\DoxyCodeLine{89 \};}
\DoxyCodeLine{90 }
\DoxyCodeLine{91 \textcolor{preprocessor}{\#endif  }\textcolor{comment}{// PWM\_DEVICE\_H}}

\end{DoxyCode}

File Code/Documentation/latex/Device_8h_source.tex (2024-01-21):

\hypertarget{Device_8h_source}{}\doxysection{Device.\+h}
\mbox{\hyperlink{Device_8h}{Go to the documentation of this file.}}
\begin{DoxyCode}{0}
\DoxyCodeLine{1 }
\DoxyCodeLine{11 \textcolor{preprocessor}{\#ifndef DEVICE\_H}}
\DoxyCodeLine{12 \textcolor{preprocessor}{\#define DEVICE\_H}}
\DoxyCodeLine{13 }
\DoxyCodeLine{14 \textcolor{preprocessor}{\#include <Arduino.h>}}
\DoxyCodeLine{15 }
\DoxyCodeLine{23 \textcolor{keyword}{class }\mbox{\hyperlink{classDevice}{Device}}}
\DoxyCodeLine{24 \{}
\DoxyCodeLine{25   \textcolor{keyword}{private}:}
\DoxyCodeLine{26     uint8\_t pinNo;   }
\DoxyCodeLine{27     \textcolor{keywordtype}{bool} state;      }
\DoxyCodeLine{28     }
\DoxyCodeLine{29   \textcolor{keyword}{public}:}
\DoxyCodeLine{35     \mbox{\hyperlink{classDevice_a3a9a4c33baf85414c1be2ff603e672bb}{Device}}(uint8\_t pinNo);}
\DoxyCodeLine{36 }
\DoxyCodeLine{37 }
\DoxyCodeLine{42     \textcolor{keyword}{virtual} \textcolor{keywordtype}{void} \mbox{\hyperlink{classDevice_a6b0a2674f57504a5df08f62e85d98578}{turnOn}}();}
\DoxyCodeLine{43 }
\DoxyCodeLine{48     \textcolor{keywordtype}{void} \mbox{\hyperlink{classDevice_a94ab5a01517645d57f8ddbf7218bde85}{turnOff}}();}
\DoxyCodeLine{49 }
\DoxyCodeLine{50 }
\DoxyCodeLine{57     \textcolor{keywordtype}{bool} \mbox{\hyperlink{classDevice_a986c707389d48b80ee07aa688cffeb10}{isOn}}();}
\DoxyCodeLine{58 }
\DoxyCodeLine{59 }
\DoxyCodeLine{67     \textcolor{keywordtype}{void} \mbox{\hyperlink{classDevice_aea74c0f721041d784c16b487a955b314}{toggle}}();}
\DoxyCodeLine{68 \};}
\DoxyCodeLine{69 }
\DoxyCodeLine{70 \textcolor{preprocessor}{\#endif }\textcolor{comment}{// DEVICE\_H}}

\end{DoxyCode}

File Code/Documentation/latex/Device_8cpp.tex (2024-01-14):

\hypertarget{Device_8cpp}{}\doxysection{Device.\+cpp File Reference}
\label{Device_8cpp}\index{Device.cpp@{Device.cpp}}

Implements the \mbox{\hyperlink{classDevice}{Device}} class.  

{\ttfamily \#include \char`\"{}Device.\+h\char`\"{}}\newline
Include dependency graph for Device.\+cpp\+:\nopagebreak
\begin{figure}[H]
\begin{center}
\leavevmode

\end{center}
\end{figure}

\doxysubsection{Detailed Description}
Implements the \mbox{\hyperlink{classDevice}{Device}} class. 

\begin{DoxyAuthor}{Author}
Sean Price 
\end{DoxyAuthor}
\begin{DoxyVersion}{Version}
0.\+1 
\end{DoxyVersion}
\begin{DoxyDate}{Date}
13/01/2024 
\end{DoxyDate}

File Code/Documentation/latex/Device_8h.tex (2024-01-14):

\hypertarget{Device_8h}{}\doxysection{Device.\+h File Reference}
\label{Device_8h}\index{Device.h@{Device.h}}

Defines the \mbox{\hyperlink{classDevice}{Device}} class.  

{\ttfamily \#include $<$Arduino.\+h$>$}\newline
Include dependency graph for Device.\+h\+:\nopagebreak
\begin{figure}[H]
\begin{center}
\leavevmode

\end{center}
\end{figure}
This graph shows which files directly or indirectly include this file\+:
\nopagebreak
\begin{figure}[H]
\begin{center}
\leavevmode
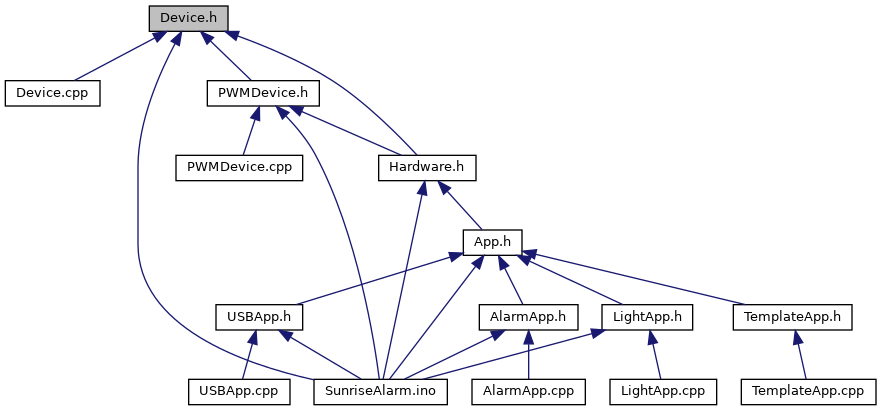
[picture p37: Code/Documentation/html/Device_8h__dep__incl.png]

\end{center}
\end{figure}
\doxysubsection*{Classes}
\begin{DoxyCompactItemize}
\item 
class \mbox{\hyperlink{classDevice}{Device}}
\begin{DoxyCompactList}\small\item\em A class representing a digital output device connected to a pin on the microcontroller. \end{DoxyCompactList}\end{DoxyCompactItemize}

\doxysubsection{Detailed Description}
Defines the \mbox{\hyperlink{classDevice}{Device}} class. 

\begin{DoxyAuthor}{Author}
Sean Price 
\end{DoxyAuthor}
\begin{DoxyVersion}{Version}
0.\+1 
\end{DoxyVersion}
\begin{DoxyDate}{Date}
13/01/2024 
\end{DoxyDate}

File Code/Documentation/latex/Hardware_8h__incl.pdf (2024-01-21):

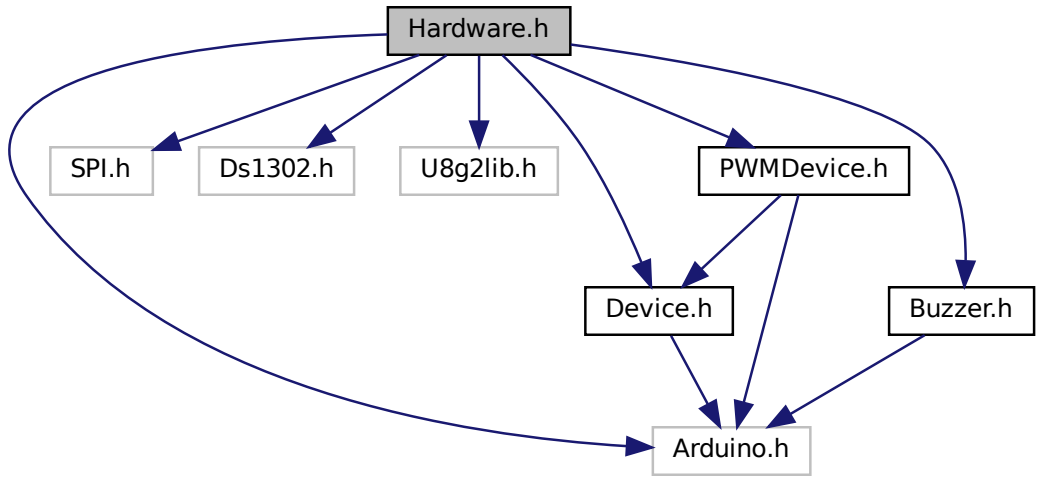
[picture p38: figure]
Hardware.h; Arduino.h; SPI.h; U8g2lib.h; Device.h; PWMDevice.h; Buzzer.h

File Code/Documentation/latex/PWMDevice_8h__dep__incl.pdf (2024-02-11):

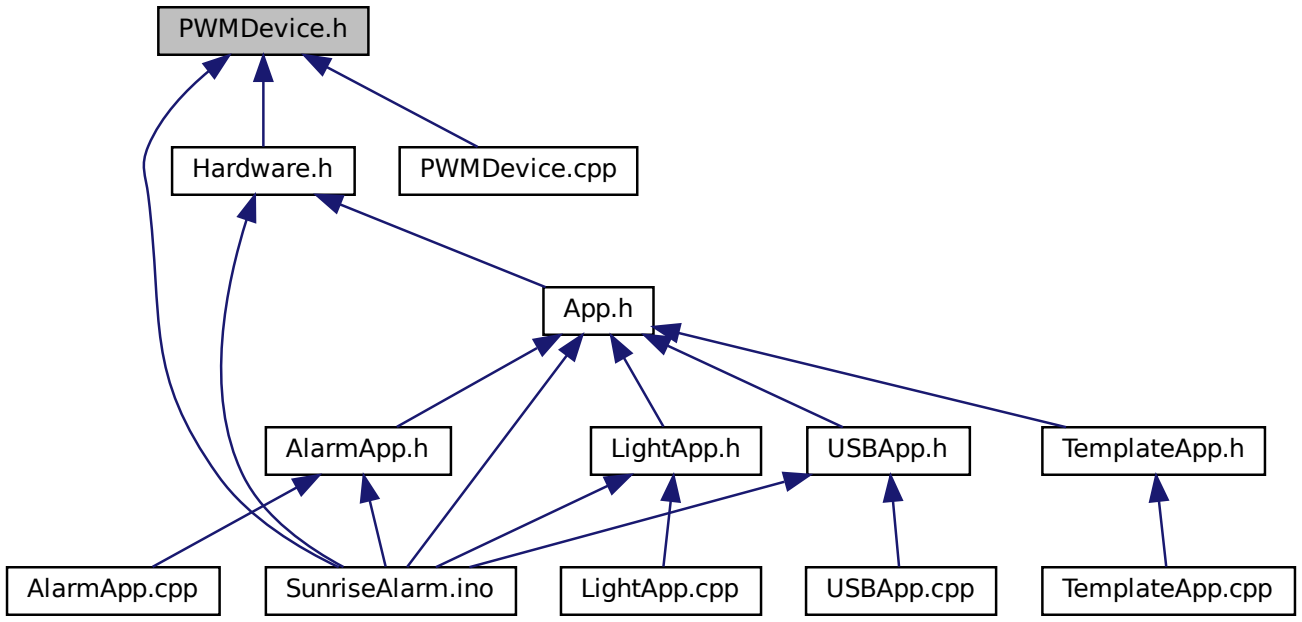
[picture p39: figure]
PWMDevice.h; Hardware.h; SunriseAlarm.ino; PWMDevice.cpp; App.h; AlarmApp.h; LightApp.h; USBApp.h; TemplateApp.h; AlarmApp.cpp; LightApp.cpp; USBApp.cpp; TemplateApp.cpp

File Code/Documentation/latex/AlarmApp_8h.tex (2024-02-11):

\hypertarget{AlarmApp_8h}{}\doxysection{Alarm\+App.\+h File Reference}
\label{AlarmApp_8h}\index{AlarmApp.h@{AlarmApp.h}}

Defines the \mbox{\hyperlink{classAlarmApp}{Alarm\+App}} class which is derrived from the \mbox{\hyperlink{classApp}{App}} base class.  

{\ttfamily \#include $<$Arduino.\+h$>$}\newline
{\ttfamily \#include \char`\"{}App.\+h\char`\"{}}\newline
Include dependency graph for Alarm\+App.\+h\+:\nopagebreak
\begin{figure}[H]
\begin{center}
\leavevmode
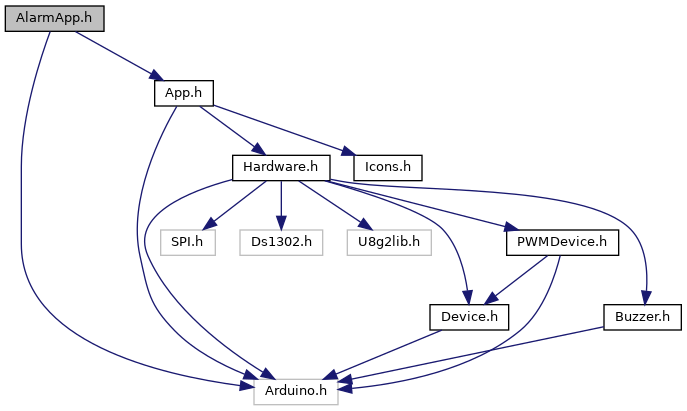
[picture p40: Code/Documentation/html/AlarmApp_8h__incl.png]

\end{center}
\end{figure}
This graph shows which files directly or indirectly include this file\+:\nopagebreak
\begin{figure}[H]
\begin{center}
\leavevmode

\end{center}
\end{figure}
\doxysubsection*{Classes}
\begin{DoxyCompactItemize}
\item 
class \mbox{\hyperlink{classAlarmApp}{Alarm\+App}}
\begin{DoxyCompactList}\small\item\em Represents an application for controlling an Alarm, derived from the \mbox{\hyperlink{classApp}{App}} base class. \end{DoxyCompactList}\end{DoxyCompactItemize}

\doxysubsection{Detailed Description}
Defines the \mbox{\hyperlink{classAlarmApp}{Alarm\+App}} class which is derrived from the \mbox{\hyperlink{classApp}{App}} base class. 

\begin{DoxyAuthor}{Author}
Sean Price 
\end{DoxyAuthor}
\begin{DoxyVersion}{Version}
0.\+1 
\end{DoxyVersion}
\begin{DoxyDate}{Date}
14/01/2024 
\end{DoxyDate}

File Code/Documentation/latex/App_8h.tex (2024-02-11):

\hypertarget{App_8h}{}\doxysection{App.\+h File Reference}
\label{App_8h}\index{App.h@{App.h}}

Implements the concrete functions from the \mbox{\hyperlink{classApp}{App}} base class.  

{\ttfamily \#include $<$Arduino.\+h$>$}\newline
{\ttfamily \#include \char`\"{}Hardware.\+h\char`\"{}}\newline
{\ttfamily \#include \char`\"{}Icons.\+h\char`\"{}}\newline
Include dependency graph for App.\+h\+:\nopagebreak
\begin{figure}[H]
\begin{center}
\leavevmode
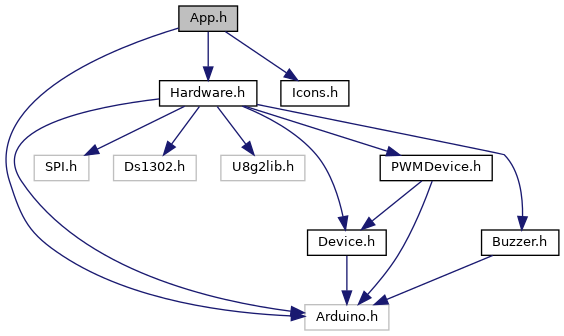
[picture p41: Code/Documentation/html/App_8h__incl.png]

\end{center}
\end{figure}
This graph shows which files directly or indirectly include this file\+:
\nopagebreak
\begin{figure}[H]
\begin{center}
\leavevmode
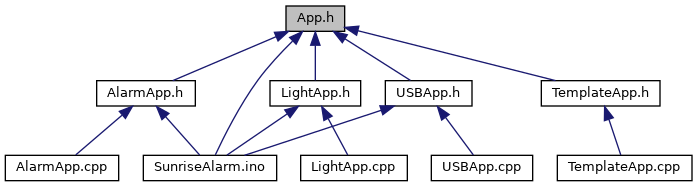
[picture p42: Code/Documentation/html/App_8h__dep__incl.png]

\end{center}
\end{figure}
\doxysubsection*{Classes}
\begin{DoxyCompactItemize}
\item 
class \mbox{\hyperlink{classApp}{App}}
\begin{DoxyCompactList}\small\item\em Abstract base class for applications. \end{DoxyCompactList}\end{DoxyCompactItemize}

\doxysubsection{Detailed Description}
Implements the concrete functions from the \mbox{\hyperlink{classApp}{App}} base class. 

Defines the \mbox{\hyperlink{classApp}{App}} base class.

\begin{DoxyAuthor}{Author}
Sean Price 
\end{DoxyAuthor}
\begin{DoxyVersion}{Version}
0.\+1 
\end{DoxyVersion}
\begin{DoxyDate}{Date}
13/01/2024 
\end{DoxyDate}

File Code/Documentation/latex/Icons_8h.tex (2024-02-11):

\hypertarget{Icons_8h}{}\doxysection{Icons.\+h File Reference}
\label{Icons_8h}\index{Icons.h@{Icons.h}}

Contains icon data for various symbols.  

This graph shows which files directly or indirectly include this file\+:
\nopagebreak
\begin{figure}[H]
\begin{center}
\leavevmode
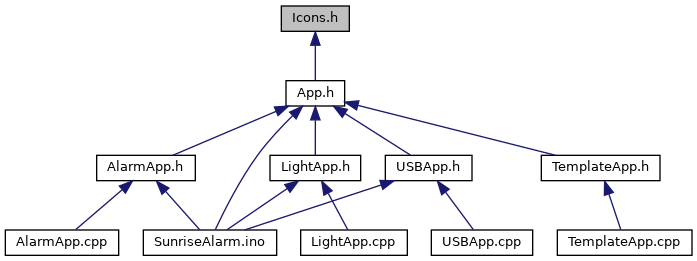
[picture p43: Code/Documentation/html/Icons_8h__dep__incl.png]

\end{center}
\end{figure}
\doxysubsection*{Variables}
\begin{DoxyCompactItemize}
\item 
const uint8\+\_\+t alarm\+Off\+Icon\mbox{[}$\,$\mbox{]} \mbox{\hyperlink{Icons_8h_a3356068d0791e8a961d4f5bdc8505e3a}{PROGMEM}}
\end{DoxyCompactItemize}

\doxysubsection{Detailed Description}
Contains icon data for various symbols. 

\begin{DoxyAuthor}{Author}
Sean Price 
\end{DoxyAuthor}
\begin{DoxyVersion}{Version}
0.\+1 
\end{DoxyVersion}
\begin{DoxyDate}{Date}
13/01/2024 
\end{DoxyDate}

\doxysubsection{Variable Documentation}
\mbox{\Hypertarget{Icons_8h_a3356068d0791e8a961d4f5bdc8505e3a}\label{Icons_8h_a3356068d0791e8a961d4f5bdc8505e3a}} 
\index{Icons.h@{Icons.h}!PROGMEM@{PROGMEM}}
\index{PROGMEM@{PROGMEM}!Icons.h@{Icons.h}}
\doxysubsubsection{\texorpdfstring{PROGMEM}{PROGMEM}}
{\footnotesize\ttfamily const uint8\+\_\+t usb\+Menu\+Icon \mbox{[}$\,$\mbox{]} PROGMEM}

{\bfseries Initial value\+:}
\begin{DoxyCode}{0}
\DoxyCodeLine{= \{}
\DoxyCodeLine{  0x00, 0x80, 0x01, 0xc0, 0x07, 0x70, 0x04, 0x10, 0x0c, 0x18, 0x08, 0x08, 0x08, 0x08, 0x08, 0x08, }
\DoxyCodeLine{  0x08, 0x08, 0x08, 0x08, 0x18, 0x0c, 0x30, 0x06, 0x60, 0x03, 0x7f, 0xff, 0x00, 0xf0, 0x00, 0x60}
\DoxyCodeLine{\}}

\end{DoxyCode}

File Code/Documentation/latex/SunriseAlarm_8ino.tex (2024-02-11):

\hypertarget{SunriseAlarm_8ino}{}\doxysection{Sunrise\+Alarm.\+ino File Reference}
\label{SunriseAlarm_8ino}\index{SunriseAlarm.ino@{SunriseAlarm.ino}}

Software to run on the Sunrise Alarm V3.  

{\ttfamily \#include $<$SPI.\+h$>$}\newline
{\ttfamily \#include $<$Ds1302.\+h$>$}\newline
{\ttfamily \#include $<$U8g2lib.\+h$>$}\newline
{\ttfamily \#include \char`\"{}Device.\+h\char`\"{}}\newline
{\ttfamily \#include \char`\"{}PWMDevice.\+h\char`\"{}}\newline
{\ttfamily \#include \char`\"{}Buzzer.\+h\char`\"{}}\newline
{\ttfamily \#include \char`\"{}Hardware.\+h\char`\"{}}\newline
{\ttfamily \#include \char`\"{}App.\+h\char`\"{}}\newline
{\ttfamily \#include \char`\"{}Light\+App.\+h\char`\"{}}\newline
{\ttfamily \#include \char`\"{}Alarm\+App.\+h\char`\"{}}\newline
{\ttfamily \#include \char`\"{}USBApp.\+h\char`\"{}}\newline
Include dependency graph for Sunrise\+Alarm.\+ino\+:
\nopagebreak
\begin{figure}[H]
\begin{center}
\leavevmode
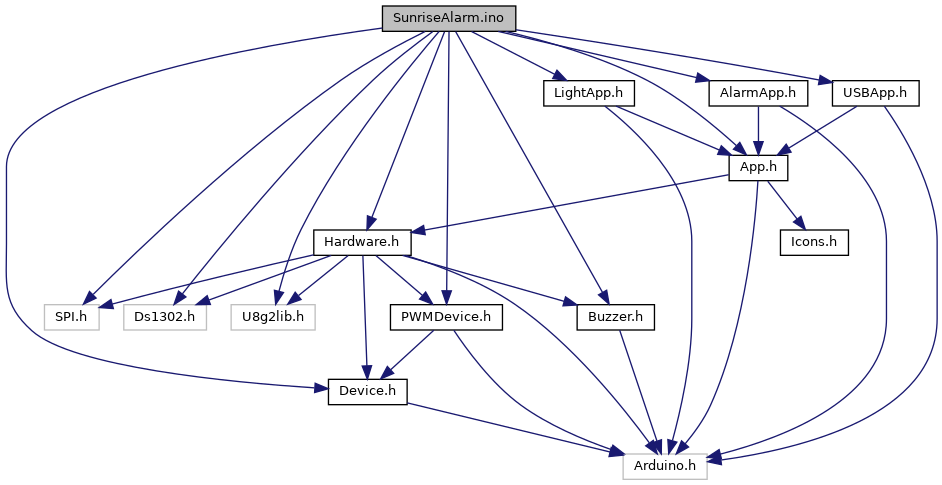
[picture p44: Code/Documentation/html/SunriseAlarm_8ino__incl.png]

\end{center}
\end{figure}
\doxysubsection*{Macros}
\begin{DoxyCompactItemize}
\item 
\mbox{\Hypertarget{SunriseAlarm_8ino_abbc8382ae4ea521f03c119a14478b759}\label{SunriseAlarm_8ino_abbc8382ae4ea521f03c119a14478b759}} 
\#define {\bfseries LEFT\+\_\+\+BUTTON}~15
\item 
\mbox{\Hypertarget{SunriseAlarm_8ino_aea4935ff922fa4fbbc0f03fc250e268b}\label{SunriseAlarm_8ino_aea4935ff922fa4fbbc0f03fc250e268b}} 
\#define {\bfseries MIDDLE\+\_\+\+BUTTON}~14
\item 
\mbox{\Hypertarget{SunriseAlarm_8ino_aeb17351958162535ab6af2cd6b030955}\label{SunriseAlarm_8ino_aeb17351958162535ab6af2cd6b030955}} 
\#define {\bfseries RIGHT\+\_\+\+BUTTON}~13
\item 
\mbox{\Hypertarget{SunriseAlarm_8ino_abc98e3adbe205cd3ab83d97150d0a845}\label{SunriseAlarm_8ino_abc98e3adbe205cd3ab83d97150d0a845}} 
\#define {\bfseries LIGHT}~11
\item 
\mbox{\Hypertarget{SunriseAlarm_8ino_aefe0ee0ec80e2a3c4330bbbd93cf4302}\label{SunriseAlarm_8ino_aefe0ee0ec80e2a3c4330bbbd93cf4302}} 
\#define {\bfseries USB\+\_\+1}~5
\item 
\mbox{\Hypertarget{SunriseAlarm_8ino_ade5022e2cda1f572702c12ed0512b874}\label{SunriseAlarm_8ino_ade5022e2cda1f572702c12ed0512b874}} 
\#define {\bfseries USB\+\_\+2}~28
\item 
\mbox{\Hypertarget{SunriseAlarm_8ino_a145103118f6d9d1129aa4509cf214a13}\label{SunriseAlarm_8ino_a145103118f6d9d1129aa4509cf214a13}} 
\#define {\bfseries BUZZER}~22
\item 
\mbox{\Hypertarget{SunriseAlarm_8ino_ac6065f56f7445de1fcbfd3cb32f57249}\label{SunriseAlarm_8ino_ac6065f56f7445de1fcbfd3cb32f57249}} 
\#define {\bfseries RTC\+\_\+\+RESET}~8
\item 
\mbox{\Hypertarget{SunriseAlarm_8ino_a80e62c38e7452c92057864f26034ee82}\label{SunriseAlarm_8ino_a80e62c38e7452c92057864f26034ee82}} 
\#define {\bfseries RTC\+\_\+\+CLK}~6
\item 
\mbox{\Hypertarget{SunriseAlarm_8ino_aa6e7096882c10a7c82c33f3589694b6e}\label{SunriseAlarm_8ino_aa6e7096882c10a7c82c33f3589694b6e}} 
\#define {\bfseries RTC\+\_\+\+DATA}~7
\item 
\mbox{\Hypertarget{SunriseAlarm_8ino_a2cd109632a6dcccaa80b43561b1ab700}\label{SunriseAlarm_8ino_a2cd109632a6dcccaa80b43561b1ab700}} 
\#define {\bfseries SCREEN\+\_\+\+WIDTH}~128
\item 
\mbox{\Hypertarget{SunriseAlarm_8ino_a6974d08a74da681b3957b2fead2608b8}\label{SunriseAlarm_8ino_a6974d08a74da681b3957b2fead2608b8}} 
\#define {\bfseries SCREEN\+\_\+\+HEIGHT}~128
\item 
\mbox{\Hypertarget{SunriseAlarm_8ino_a48b0ba88a54a3a338000c1737696459b}\label{SunriseAlarm_8ino_a48b0ba88a54a3a338000c1737696459b}} 
\#define {\bfseries SCREEN\+\_\+\+CLK}~18
\item 
\mbox{\Hypertarget{SunriseAlarm_8ino_a405ed6402b18dfe4db336ff1a5eb677a}\label{SunriseAlarm_8ino_a405ed6402b18dfe4db336ff1a5eb677a}} 
\#define {\bfseries SCREEN\+\_\+\+DATA}~19
\item 
\mbox{\Hypertarget{SunriseAlarm_8ino_af7e65fedb982eb81a0b2026650e84fc9}\label{SunriseAlarm_8ino_af7e65fedb982eb81a0b2026650e84fc9}} 
\#define {\bfseries SCREEN\+\_\+\+CS}~16
\item 
\mbox{\Hypertarget{SunriseAlarm_8ino_ac4bb91df9d3c56152d198c189da7279f}\label{SunriseAlarm_8ino_ac4bb91df9d3c56152d198c189da7279f}} 
\#define {\bfseries SCREEN\+\_\+\+DC}~17
\item 
\mbox{\Hypertarget{SunriseAlarm_8ino_acc6682a301992c99896fb7496ed6887f}\label{SunriseAlarm_8ino_acc6682a301992c99896fb7496ed6887f}} 
\#define {\bfseries SCREEN\+\_\+\+RESET}~20
\end{DoxyCompactItemize}
\doxysubsection*{Functions}
\begin{DoxyCompactItemize}
\item 
\mbox{\Hypertarget{SunriseAlarm_8ino_af085aef2eb735ef5630c4f5b05e0f4cd}\label{SunriseAlarm_8ino_af085aef2eb735ef5630c4f5b05e0f4cd}} 
U8\+G2\+\_\+\+SSD1327\+\_\+\+WS\+\_\+128\+X128\+\_\+\+F\+\_\+4\+W\+\_\+\+SW\+\_\+\+SPI {\bfseries display} (U8\+G2\+\_\+\+R0, SCREEN\+\_\+\+CLK, SCREEN\+\_\+\+DATA, SCREEN\+\_\+\+CS, SCREEN\+\_\+\+DC, SCREEN\+\_\+\+RESET)
\item 
\mbox{\Hypertarget{SunriseAlarm_8ino_a7398847714bda16bd4e4303b9da2429a}\label{SunriseAlarm_8ino_a7398847714bda16bd4e4303b9da2429a}} 
Ds1302 {\bfseries rtc} (RTC\+\_\+\+RESET, RTC\+\_\+\+CLK, RTC\+\_\+\+DATA)
\item 
\mbox{\Hypertarget{SunriseAlarm_8ino_a4fc01d736fe50cf5b977f755b675f11d}\label{SunriseAlarm_8ino_a4fc01d736fe50cf5b977f755b675f11d}} 
void {\bfseries setup} ()
\item 
\mbox{\Hypertarget{SunriseAlarm_8ino_afe461d27b9c48d5921c00d521181f12f}\label{SunriseAlarm_8ino_afe461d27b9c48d5921c00d521181f12f}} 
void {\bfseries loop} ()
\item 
\mbox{\Hypertarget{SunriseAlarm_8ino_ab7eb3c8c2e8604801ee00f11d3af8c3f}\label{SunriseAlarm_8ino_ab7eb3c8c2e8604801ee00f11d3af8c3f}} 
void {\bfseries update\+Display} ()
\item 
\mbox{\Hypertarget{SunriseAlarm_8ino_a3a9b647a28587c3704f3dc080cebe906}\label{SunriseAlarm_8ino_a3a9b647a28587c3704f3dc080cebe906}} 
bool {\bfseries any\+Button\+Pressed} ()
\item 
\mbox{\Hypertarget{SunriseAlarm_8ino_ab2ce40bc0236a98ba8aeadb4a4e2733e}\label{SunriseAlarm_8ino_ab2ce40bc0236a98ba8aeadb4a4e2733e}} 
void {\bfseries left\+ISR} ()
\item 
\mbox{\Hypertarget{SunriseAlarm_8ino_afae4a2333f7612aa057f799ddee5e737}\label{SunriseAlarm_8ino_afae4a2333f7612aa057f799ddee5e737}} 
void {\bfseries middle\+ISR} ()
\item 
\mbox{\Hypertarget{SunriseAlarm_8ino_a90503c0ac45681923b9e3fc5d6f9fd3e}\label{SunriseAlarm_8ino_a90503c0ac45681923b9e3fc5d6f9fd3e}} 
void {\bfseries right\+ISR} ()
\end{DoxyCompactItemize}
\doxysubsection*{Variables}
\begin{DoxyCompactItemize}
\item 
\mbox{\Hypertarget{SunriseAlarm_8ino_a6529c4101a37a5d89aaca48bbd0836f2}\label{SunriseAlarm_8ino_a6529c4101a37a5d89aaca48bbd0836f2}} 
\mbox{\hyperlink{classPWMDevice}{PWMDevice}} {\bfseries light} (LIGHT, 4)
\item 
\mbox{\Hypertarget{SunriseAlarm_8ino_a852b4013c5aa5c7427cc164e357520a3}\label{SunriseAlarm_8ino_a852b4013c5aa5c7427cc164e357520a3}} 
\mbox{\hyperlink{classDevice}{Device}} {\bfseries usb1} (USB\+\_\+1)
\item 
\mbox{\Hypertarget{SunriseAlarm_8ino_a2a677b1473f90a43159877c6b491c0d9}\label{SunriseAlarm_8ino_a2a677b1473f90a43159877c6b491c0d9}} 
\mbox{\hyperlink{classDevice}{Device}} {\bfseries usb2} (USB\+\_\+2)
\item 
\mbox{\Hypertarget{SunriseAlarm_8ino_a9864dfd8340691ad3a7b9f6db2cd20e1}\label{SunriseAlarm_8ino_a9864dfd8340691ad3a7b9f6db2cd20e1}} 
\mbox{\hyperlink{classBuzzer}{Buzzer}} {\bfseries buzzer} (BUZZER)
\item 
\mbox{\Hypertarget{SunriseAlarm_8ino_ae6cbe7d5ac57ec70044cee01ac1bd056}\label{SunriseAlarm_8ino_ae6cbe7d5ac57ec70044cee01ac1bd056}} 
struct \mbox{\hyperlink{structHardware}{Hardware}} {\bfseries hw} = \{display, rtc, light, usb1, usb2, buzzer\}
\item 
\mbox{\Hypertarget{SunriseAlarm_8ino_a05e9284e72e093417461a3599214d38f}\label{SunriseAlarm_8ino_a05e9284e72e093417461a3599214d38f}} 
\mbox{\hyperlink{classAlarmApp}{Alarm\+App}} {\bfseries alarm\+App} (hw)
\item 
\mbox{\Hypertarget{SunriseAlarm_8ino_aa491d2bef3ac3c1b81c07681aef5846b}\label{SunriseAlarm_8ino_aa491d2bef3ac3c1b81c07681aef5846b}} 
\mbox{\hyperlink{classLightApp}{Light\+App}} {\bfseries light\+App} (hw)
\item 
\mbox{\Hypertarget{SunriseAlarm_8ino_a7944c55f065d6c946880a3bf7ead82c0}\label{SunriseAlarm_8ino_a7944c55f065d6c946880a3bf7ead82c0}} 
\mbox{\hyperlink{classUSBApp}{USBApp}} {\bfseries usb\+App} (hw)
\item 
\mbox{\Hypertarget{SunriseAlarm_8ino_a32aa95f939b279598dfe4730276853e2}\label{SunriseAlarm_8ino_a32aa95f939b279598dfe4730276853e2}} 
const int {\bfseries no\+Of\+Apps} = 3
\item 
\mbox{\Hypertarget{SunriseAlarm_8ino_a2d27d9f0cb76dc546d082b5743fb0c9e}\label{SunriseAlarm_8ino_a2d27d9f0cb76dc546d082b5743fb0c9e}} 
\mbox{\hyperlink{classApp}{App}} $\ast$ {\bfseries apps} \mbox{[}no\+Of\+Apps\mbox{]}
\item 
\mbox{\Hypertarget{SunriseAlarm_8ino_a9156ed676621e3b218e057a4e2094776}\label{SunriseAlarm_8ino_a9156ed676621e3b218e057a4e2094776}} 
uint8\+\_\+t {\bfseries current\+App} = 0
\item 
\mbox{\Hypertarget{SunriseAlarm_8ino_af065086ee579e71ebd05952f6a4513f3}\label{SunriseAlarm_8ino_af065086ee579e71ebd05952f6a4513f3}} 
volatile bool {\bfseries left\+Pressed} = false
\item 
\mbox{\Hypertarget{SunriseAlarm_8ino_a5b2d1e6d6ec719c7437bfdf8612b82be}\label{SunriseAlarm_8ino_a5b2d1e6d6ec719c7437bfdf8612b82be}} 
volatile bool {\bfseries middle\+Pressed} = false
\item 
\mbox{\Hypertarget{SunriseAlarm_8ino_a475ec524b404fbad253ac91923d52fce}\label{SunriseAlarm_8ino_a475ec524b404fbad253ac91923d52fce}} 
volatile bool {\bfseries right\+Pressed} = false
\end{DoxyCompactItemize}

\doxysubsection{Detailed Description}
Software to run on the Sunrise Alarm V3. 

\begin{DoxyAuthor}{Author}
Sean Price 
\end{DoxyAuthor}
\begin{DoxyVersion}{Version}
0.\+1 
\end{DoxyVersion}
\begin{DoxyDate}{Date}
13/01/2024
\end{DoxyDate}
The goal with this software is to make it modular and easy to add functionality in the form of \char`\"{}\+Apps\char`\"{}. This will make it possible to add new features, without breaking existing functionality.

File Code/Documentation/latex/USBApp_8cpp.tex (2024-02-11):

\hypertarget{USBApp_8cpp}{}\doxysection{USBApp.\+cpp File Reference}
\label{USBApp_8cpp}\index{USBApp.cpp@{USBApp.cpp}}

Implements the \mbox{\hyperlink{classUSBApp}{USBApp}} class.  

{\ttfamily \#include \char`\"{}USBApp.\+h\char`\"{}}\newline
Include dependency graph for USBApp.\+cpp\+:
\nopagebreak
\begin{figure}[H]
\begin{center}
\leavevmode
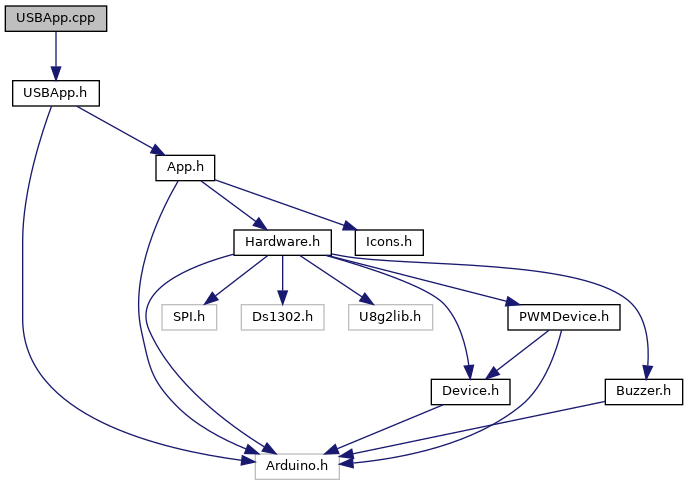
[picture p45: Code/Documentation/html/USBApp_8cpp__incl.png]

\end{center}
\end{figure}

\doxysubsection{Detailed Description}
Implements the \mbox{\hyperlink{classUSBApp}{USBApp}} class. 

\begin{DoxyAuthor}{Author}
Sean Price 
\end{DoxyAuthor}
\begin{DoxyVersion}{Version}
0.\+1 
\end{DoxyVersion}
\begin{DoxyDate}{Date}
11/02/2024 
\end{DoxyDate}

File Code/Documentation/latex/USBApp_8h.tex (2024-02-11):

\hypertarget{USBApp_8h}{}\doxysection{USBApp.\+h File Reference}
\label{USBApp_8h}\index{USBApp.h@{USBApp.h}}

Defines the \mbox{\hyperlink{classUSBApp}{USBApp}} class which is derrived from the \mbox{\hyperlink{classApp}{App}} base class.  

{\ttfamily \#include $<$Arduino.\+h$>$}\newline
{\ttfamily \#include \char`\"{}App.\+h\char`\"{}}\newline
Include dependency graph for USBApp.\+h\+:
\nopagebreak
\begin{figure}[H]
\begin{center}
\leavevmode
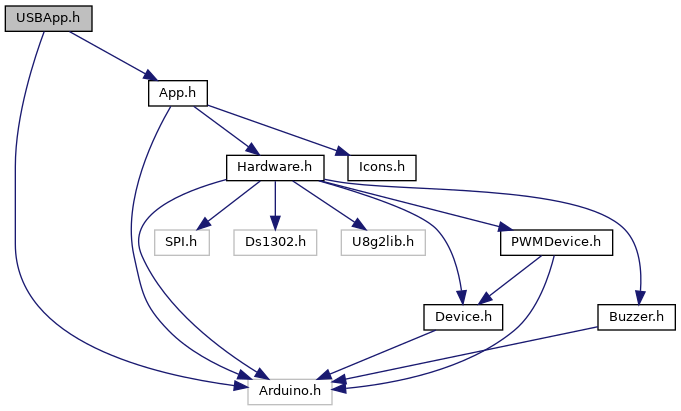
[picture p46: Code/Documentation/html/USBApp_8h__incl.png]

\end{center}
\end{figure}
This graph shows which files directly or indirectly include this file\+:
\nopagebreak
\begin{figure}[H]
\begin{center}
\leavevmode

\end{center}
\end{figure}
\doxysubsection*{Classes}
\begin{DoxyCompactItemize}
\item 
class \mbox{\hyperlink{classUSBApp}{USBApp}}
\begin{DoxyCompactList}\small\item\em Represents an application for controlling USB ports, derived from the \mbox{\hyperlink{classApp}{App}} base class. \end{DoxyCompactList}\end{DoxyCompactItemize}

\doxysubsection{Detailed Description}
Defines the \mbox{\hyperlink{classUSBApp}{USBApp}} class which is derrived from the \mbox{\hyperlink{classApp}{App}} base class. 

\begin{DoxyAuthor}{Author}
Sean Price 
\end{DoxyAuthor}
\begin{DoxyVersion}{Version}
0.\+1 
\end{DoxyVersion}
\begin{DoxyDate}{Date}
11/02/2024 
\end{DoxyDate}

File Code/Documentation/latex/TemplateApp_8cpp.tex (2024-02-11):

\hypertarget{TemplateApp_8cpp}{}\doxysection{Template\+App.\+cpp File Reference}
\label{TemplateApp_8cpp}\index{TemplateApp.cpp@{TemplateApp.cpp}}

Implements the \mbox{\hyperlink{classTemplateApp}{Template\+App}} class.  

{\ttfamily \#include \char`\"{}Template\+App.\+h\char`\"{}}\newline
Include dependency graph for Template\+App.\+cpp\+:\nopagebreak
\begin{figure}[H]
\begin{center}
\leavevmode
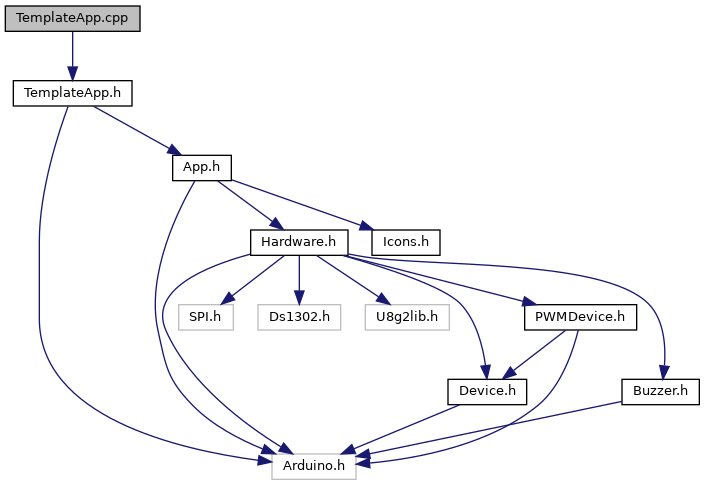
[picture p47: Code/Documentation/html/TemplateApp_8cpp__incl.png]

\end{center}
\end{figure}

\doxysubsection{Detailed Description}
Implements the \mbox{\hyperlink{classTemplateApp}{Template\+App}} class. 

\begin{DoxyAuthor}{Author}
Sean Price 
\end{DoxyAuthor}
\begin{DoxyVersion}{Version}
0.\+1 
\end{DoxyVersion}
\begin{DoxyDate}{Date}
11/02/2024
\end{DoxyDate}
This file serves as a template for creating new applications based on the \mbox{\hyperlink{classApp}{App}} base class. Follow the instructions below to create and customize your own app.

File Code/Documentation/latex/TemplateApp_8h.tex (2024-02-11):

\hypertarget{TemplateApp_8h}{}\doxysection{Template\+App.\+h File Reference}
\label{TemplateApp_8h}\index{TemplateApp.h@{TemplateApp.h}}

Defines the \mbox{\hyperlink{classTemplateApp}{Template\+App}} class which is derrived from the \mbox{\hyperlink{classApp}{App}} base class.  

{\ttfamily \#include $<$Arduino.\+h$>$}\newline
{\ttfamily \#include \char`\"{}App.\+h\char`\"{}}\newline
Include dependency graph for Template\+App.\+h\+:\nopagebreak
\begin{figure}[H]
\begin{center}
\leavevmode
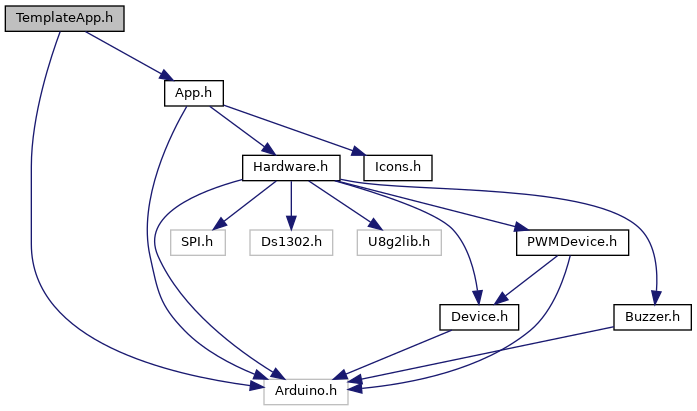
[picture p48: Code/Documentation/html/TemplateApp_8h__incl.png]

\end{center}
\end{figure}
This graph shows which files directly or indirectly include this file\+:\nopagebreak
\begin{figure}[H]
\begin{center}
\leavevmode

\end{center}
\end{figure}
\doxysubsection*{Classes}
\begin{DoxyCompactItemize}
\item 
class \mbox{\hyperlink{classTemplateApp}{Template\+App}}
\begin{DoxyCompactList}\small\item\em Represents the basic structure of an application, derived from the \mbox{\hyperlink{classApp}{App}} base class. \end{DoxyCompactList}\end{DoxyCompactItemize}

\doxysubsection{Detailed Description}
Defines the \mbox{\hyperlink{classTemplateApp}{Template\+App}} class which is derrived from the \mbox{\hyperlink{classApp}{App}} base class. 

\begin{DoxyAuthor}{Author}
Sean Price 
\end{DoxyAuthor}
\begin{DoxyVersion}{Version}
0.\+1 
\end{DoxyVersion}
\begin{DoxyDate}{Date}
11/02/2024
\end{DoxyDate}
This file serves as a template for creating new applications based on the \mbox{\hyperlink{classApp}{App}} base class. Follow the instructions below to create and customize your own app. ~\newline

HOW TO CREATE A NEW APP ~\newline

\begin{DoxyEnumerate}
\item Copy the \char`\"{}\+Template\+App.\+h\char`\"{} and \char`\"{}\+Template\+App.\+cpp\char`\"{} files, changing their names to reflect your app. ~\newline

\item Change the header guards, file headers and and include statements to the new file names. ~\newline

\item Do a find and replace for the phrase \char`\"{}\+Template\+App\char`\"{} replacing it with the name of your app (both files). ~\newline

\item Add code to each of the functions. ~\newline

\item Include the header file in the main program. ~\newline

\item Instantiate the new \char`\"{}\+\_\+\+\_\+\+\_\+\+\_\+\+App\char`\"{} object. ~\newline

\item Increment the \char`\"{}no\+Of\+Apps\char`\"{}. ~\newline

\item Add a reference to the new app object to the next index of the \char`\"{}apps\char`\"{} array. e.\+g.\char`\"{}apps\mbox{[}i\mbox{]} = \&\+\_\+\+\_\+\+\_\+\+\_\+\+App;\char`\"{}. 
\end{DoxyEnumerate}

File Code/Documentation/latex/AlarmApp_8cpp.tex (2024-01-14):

\hypertarget{AlarmApp_8cpp}{}\doxysection{Alarm\+App.\+cpp File Reference}
\label{AlarmApp_8cpp}\index{AlarmApp.cpp@{AlarmApp.cpp}}

Implements the \mbox{\hyperlink{classAlarmApp}{Alarm\+App}} class.  

{\ttfamily \#include \char`\"{}Alarm\+App.\+h\char`\"{}}\newline
Include dependency graph for Alarm\+App.\+cpp\+:\nopagebreak
\begin{figure}[H]
\begin{center}
\leavevmode
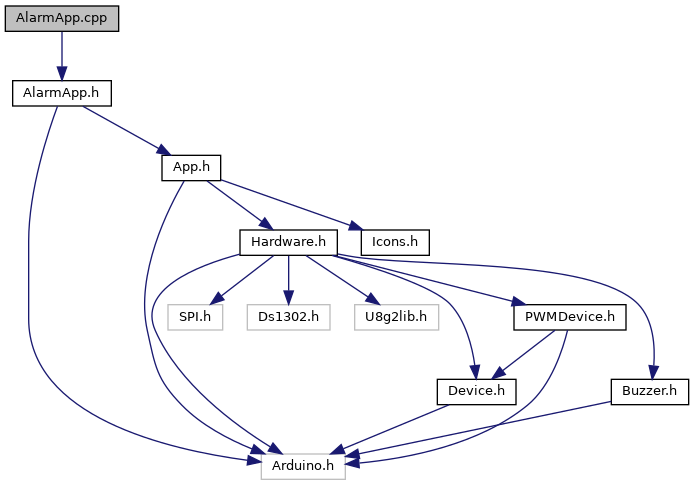
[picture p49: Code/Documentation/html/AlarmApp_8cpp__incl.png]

\end{center}
\end{figure}

\doxysubsection{Detailed Description}
Implements the \mbox{\hyperlink{classAlarmApp}{Alarm\+App}} class. 

\begin{DoxyAuthor}{Author}
Sean Price 
\end{DoxyAuthor}
\begin{DoxyVersion}{Version}
0.\+1 
\end{DoxyVersion}
\begin{DoxyDate}{Date}
14/01/2024 
\end{DoxyDate}

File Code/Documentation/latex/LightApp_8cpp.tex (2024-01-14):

\hypertarget{LightApp_8cpp}{}\doxysection{Light\+App.\+cpp File Reference}
\label{LightApp_8cpp}\index{LightApp.cpp@{LightApp.cpp}}

Implements the \mbox{\hyperlink{classLightApp}{Light\+App}} class.  

{\ttfamily \#include \char`\"{}Light\+App.\+h\char`\"{}}\newline
Include dependency graph for Light\+App.\+cpp\+:\nopagebreak
\begin{figure}[H]
\begin{center}
\leavevmode
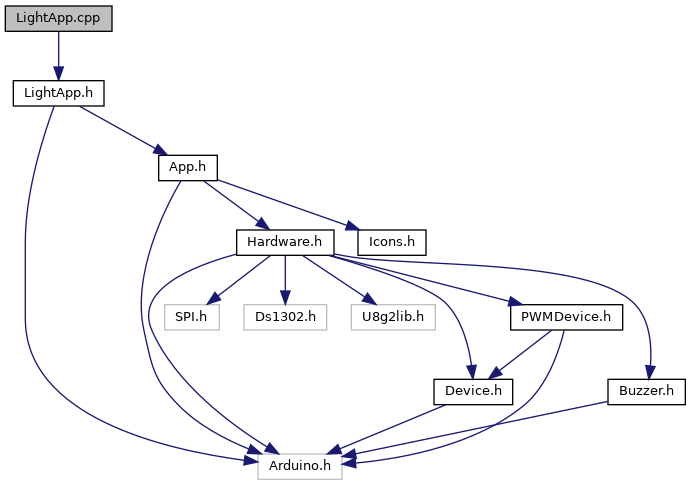
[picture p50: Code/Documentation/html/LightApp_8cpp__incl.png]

\end{center}
\end{figure}

\doxysubsection{Detailed Description}
Implements the \mbox{\hyperlink{classLightApp}{Light\+App}} class. 

\begin{DoxyAuthor}{Author}
Sean Price 
\end{DoxyAuthor}
\begin{DoxyVersion}{Version}
0.\+1 
\end{DoxyVersion}
\begin{DoxyDate}{Date}
13/01/2024 
\end{DoxyDate}

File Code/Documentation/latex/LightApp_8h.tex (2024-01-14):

\hypertarget{LightApp_8h}{}\doxysection{Light\+App.\+h File Reference}
\label{LightApp_8h}\index{LightApp.h@{LightApp.h}}

Defines the \mbox{\hyperlink{classLightApp}{Light\+App}} class which is derrived from the \mbox{\hyperlink{classApp}{App}} base class.  

{\ttfamily \#include $<$Arduino.\+h$>$}\newline
{\ttfamily \#include \char`\"{}App.\+h\char`\"{}}\newline
Include dependency graph for Light\+App.\+h\+:\nopagebreak
\begin{figure}[H]
\begin{center}
\leavevmode
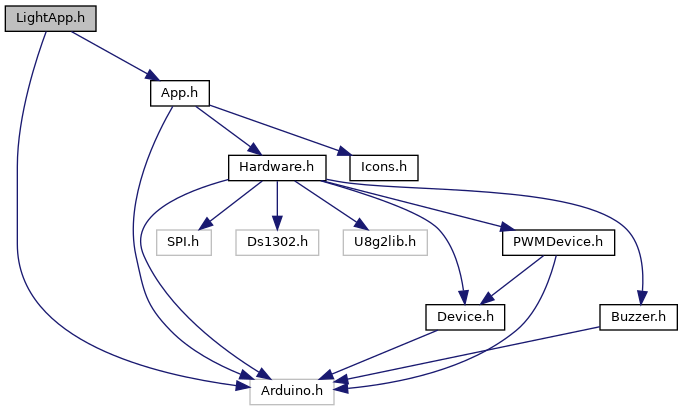
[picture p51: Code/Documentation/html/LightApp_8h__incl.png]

\end{center}
\end{figure}
This graph shows which files directly or indirectly include this file\+:\nopagebreak
\begin{figure}[H]
\begin{center}
\leavevmode

\end{center}
\end{figure}
\doxysubsection*{Classes}
\begin{DoxyCompactItemize}
\item 
class \mbox{\hyperlink{classLightApp}{Light\+App}}
\begin{DoxyCompactList}\small\item\em Represents an application for controlling a light, derived from the \mbox{\hyperlink{classApp}{App}} base class. \end{DoxyCompactList}\end{DoxyCompactItemize}

\doxysubsection{Detailed Description}
Defines the \mbox{\hyperlink{classLightApp}{Light\+App}} class which is derrived from the \mbox{\hyperlink{classApp}{App}} base class. 

\begin{DoxyAuthor}{Author}
Sean Price 
\end{DoxyAuthor}
\begin{DoxyVersion}{Version}
0.\+1 
\end{DoxyVersion}
\begin{DoxyDate}{Date}
13/01/2024 
\end{DoxyDate}

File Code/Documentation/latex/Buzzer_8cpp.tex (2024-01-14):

\hypertarget{Buzzer_8cpp}{}\doxysection{Buzzer.\+cpp File Reference}
\label{Buzzer_8cpp}\index{Buzzer.cpp@{Buzzer.cpp}}

Implements the \mbox{\hyperlink{classBuzzer}{Buzzer}} class.  

{\ttfamily \#include \char`\"{}Buzzer.\+h\char`\"{}}\newline
Include dependency graph for Buzzer.\+cpp\+:\nopagebreak
\begin{figure}[H]
\begin{center}
\leavevmode

\end{center}
\end{figure}

\doxysubsection{Detailed Description}
Implements the \mbox{\hyperlink{classBuzzer}{Buzzer}} class. 

\begin{DoxyAuthor}{Author}
Sean Price 
\end{DoxyAuthor}
\begin{DoxyVersion}{Version}
0.\+1 
\end{DoxyVersion}
\begin{DoxyDate}{Date}
13/01/2024 
\end{DoxyDate}

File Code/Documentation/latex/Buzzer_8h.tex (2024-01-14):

\hypertarget{Buzzer_8h}{}\doxysection{Buzzer.\+h File Reference}
\label{Buzzer_8h}\index{Buzzer.h@{Buzzer.h}}

Defines the \mbox{\hyperlink{classBuzzer}{Buzzer}} class.  

{\ttfamily \#include $<$Arduino.\+h$>$}\newline
Include dependency graph for Buzzer.\+h\+:\nopagebreak
\begin{figure}[H]
\begin{center}
\leavevmode

\end{center}
\end{figure}
This graph shows which files directly or indirectly include this file\+:
\nopagebreak
\begin{figure}[H]
\begin{center}
\leavevmode
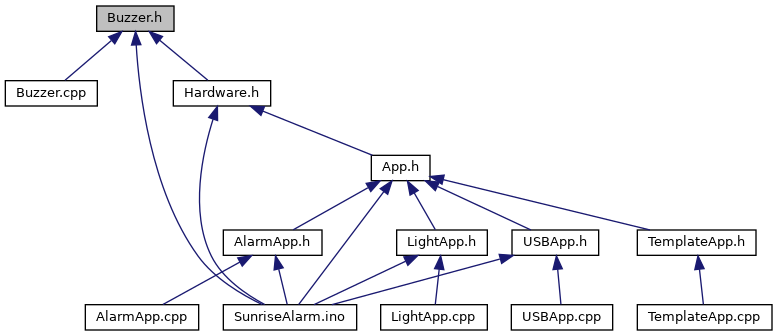
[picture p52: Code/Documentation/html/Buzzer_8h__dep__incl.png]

\end{center}
\end{figure}
\doxysubsection*{Classes}
\begin{DoxyCompactItemize}
\item 
class \mbox{\hyperlink{classBuzzer}{Buzzer}}
\begin{DoxyCompactList}\small\item\em A class representing a buzzer connected to a pin on the microcontroller. \end{DoxyCompactList}\end{DoxyCompactItemize}

\doxysubsection{Detailed Description}
Defines the \mbox{\hyperlink{classBuzzer}{Buzzer}} class. 

\begin{DoxyAuthor}{Author}
Sean Price 
\end{DoxyAuthor}
\begin{DoxyVersion}{Version}
0.\+1 
\end{DoxyVersion}
\begin{DoxyDate}{Date}
13/01/2024 
\end{DoxyDate}

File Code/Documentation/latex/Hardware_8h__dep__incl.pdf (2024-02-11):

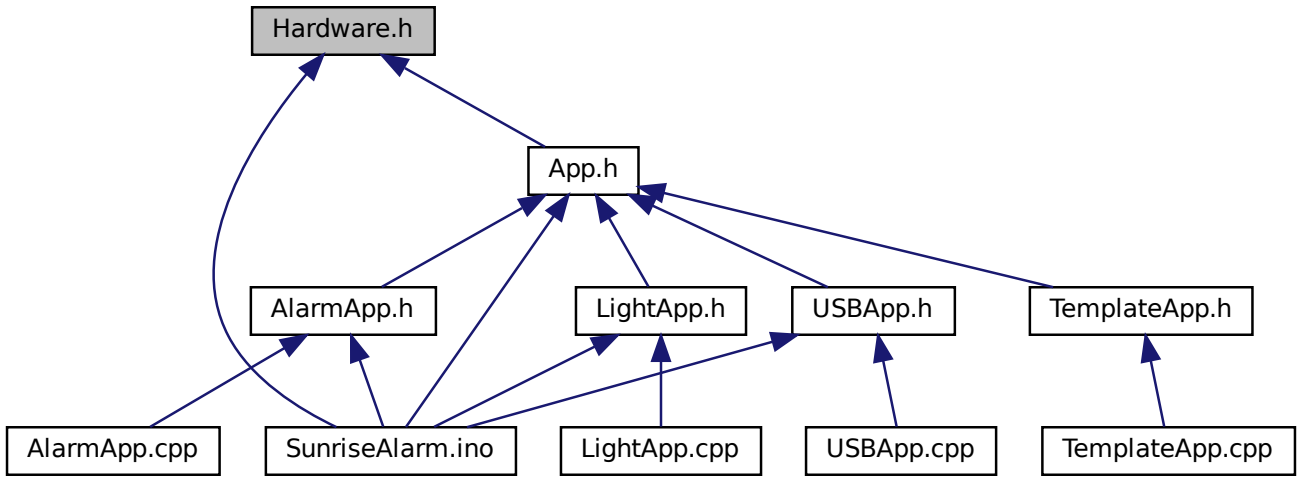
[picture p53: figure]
Hardware.h; App.h; SunriseAlarm.ino; AlarmApp.h; LightApp.h; USBApp.h; TemplateApp.h; AlarmApp.cpp; LightApp.cpp; USBApp.cpp; TemplateApp.cpp

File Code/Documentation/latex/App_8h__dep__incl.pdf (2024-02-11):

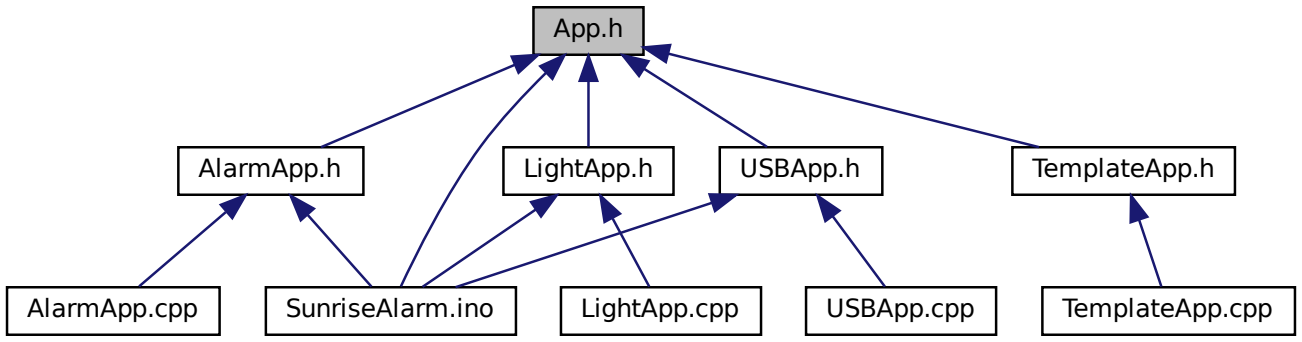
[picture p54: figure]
App.h; AlarmApp.h; SunriseAlarm.ino; LightApp.h; USBApp.h; TemplateApp.h; AlarmApp.cpp; LightApp.cpp; USBApp.cpp; TemplateApp.cpp

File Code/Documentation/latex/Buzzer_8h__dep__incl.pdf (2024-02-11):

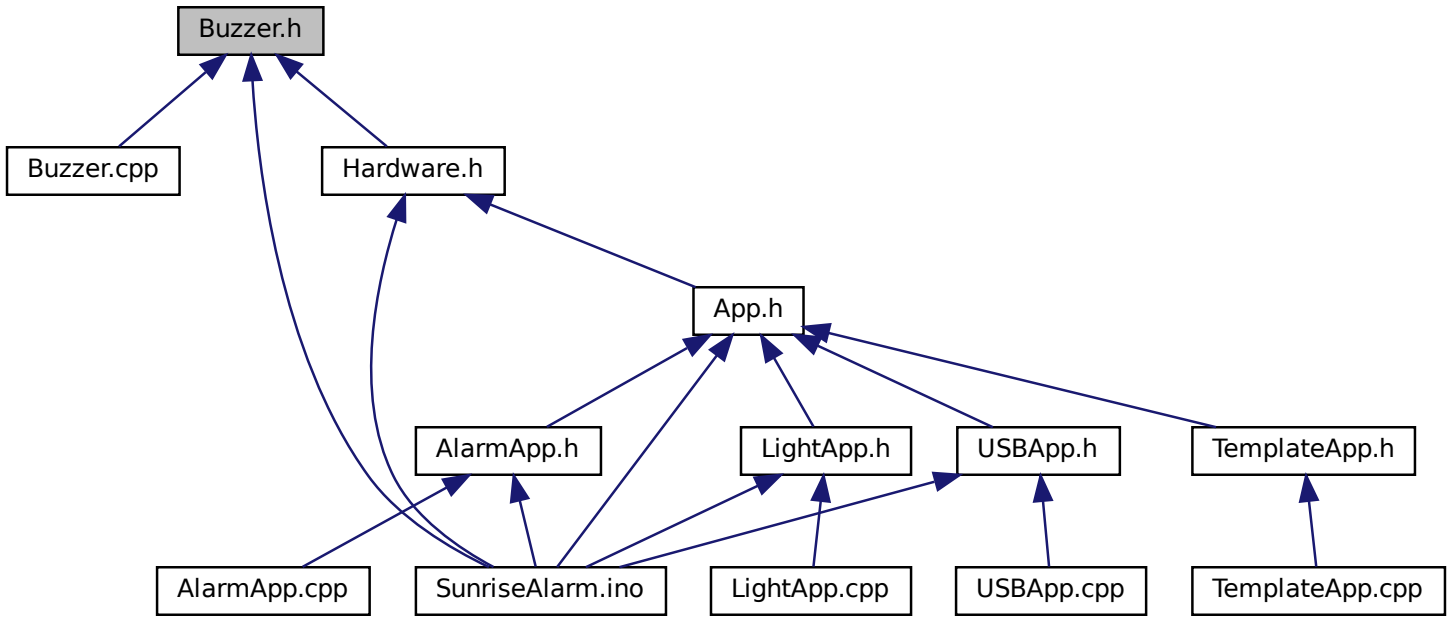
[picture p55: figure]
Buzzer.h; Buzzer.cpp; Hardware.h; SunriseAlarm.ino; App.h; AlarmApp.h; LightApp.h; USBApp.h; TemplateApp.h; AlarmApp.cpp; LightApp.cpp; USBApp.cpp; TemplateApp.cpp

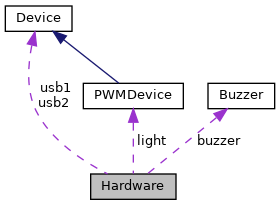
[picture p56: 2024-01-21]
Code/Documentation/html/structHardware__coll__graph.png

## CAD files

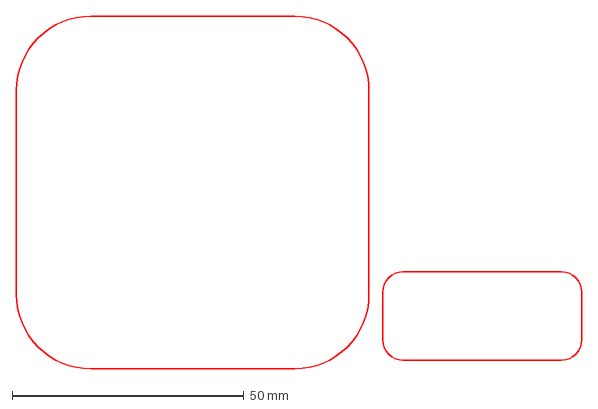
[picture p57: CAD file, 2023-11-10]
Enclosure/Acrylic_Lasercutting.dxf
121.8 x 76.0 mm

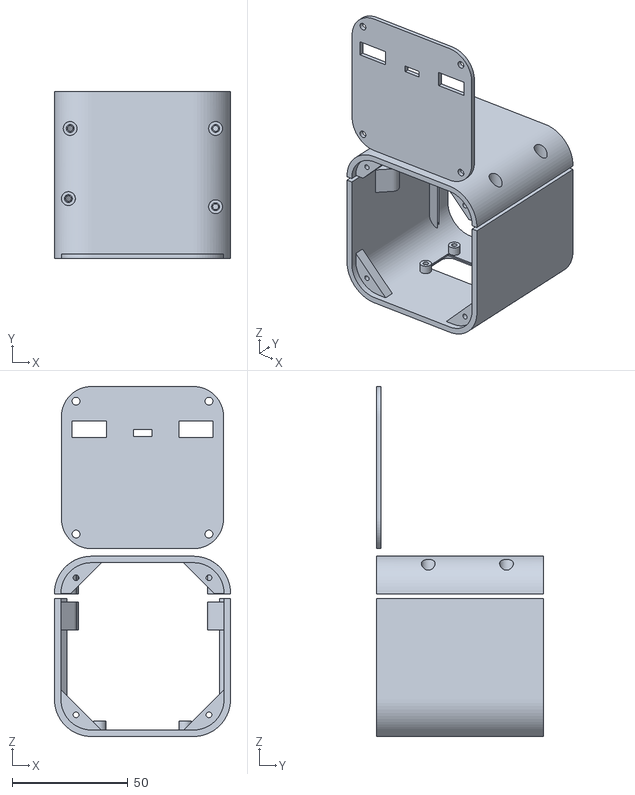
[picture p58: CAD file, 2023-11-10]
Enclosure/Sunrise_Alarm_V3_Enclosure_Printable.stl
76.0 x 72.0 x 151.0

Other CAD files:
Enclosure/Button_PCB.f3d
Enclosure/Main_PCB.f3d
Enclosure/OLED.f3d
Enclosure/Sunrise_Alarm_V3_Idea.f3d

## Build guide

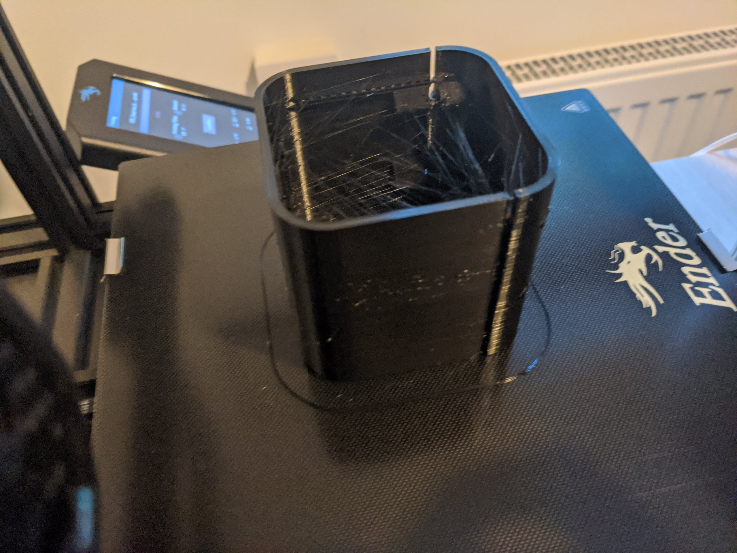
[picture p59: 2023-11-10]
Images/3D_Printing.jpg

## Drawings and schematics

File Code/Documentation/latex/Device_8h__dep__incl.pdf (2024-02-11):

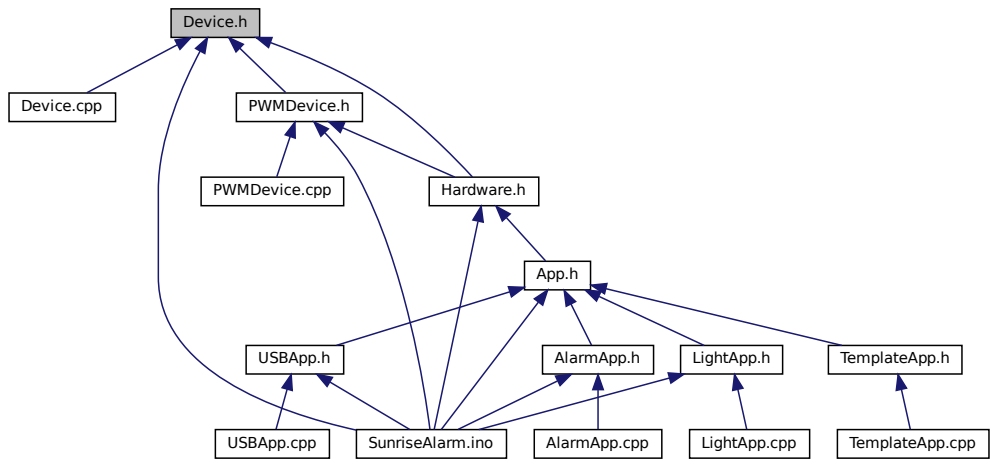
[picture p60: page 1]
Device.h; Device.cpp; Hardware.h; SunriseAlarm.ino; PWMDevice.h; App.h; USBApp.h; AlarmApp.h; LightApp.h; TemplateApp.h; USBApp.cpp; AlarmApp.cpp; LightApp.cpp; TemplateApp.cpp; PWMDevice.cpp

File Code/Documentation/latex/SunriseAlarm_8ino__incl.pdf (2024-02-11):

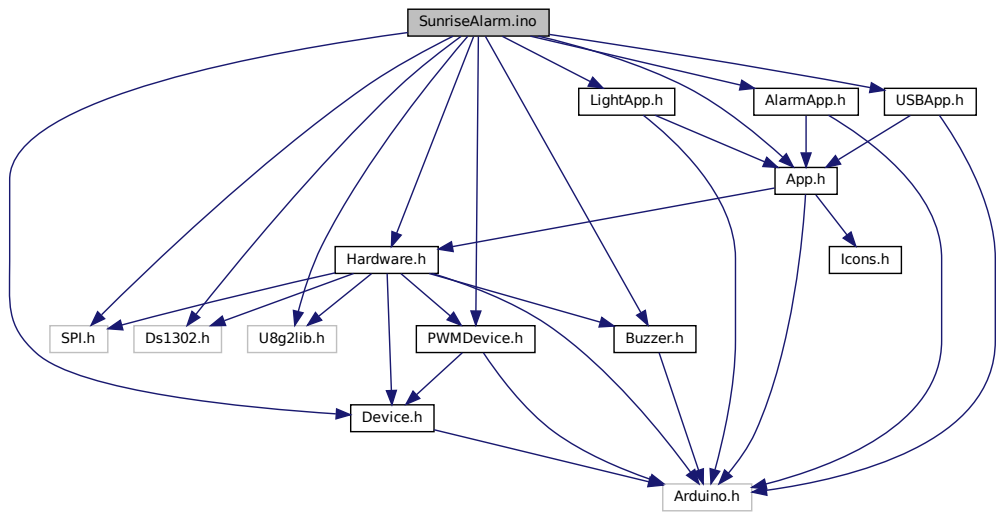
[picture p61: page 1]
SunriseAlarm.ino; SPI.h; U8g2lib.h; Device.h; PWMDevice.h; Buzzer.h; Hardware.h; App.h; LightApp.h; AlarmApp.h; USBApp.h; Arduino.h; Icons.h

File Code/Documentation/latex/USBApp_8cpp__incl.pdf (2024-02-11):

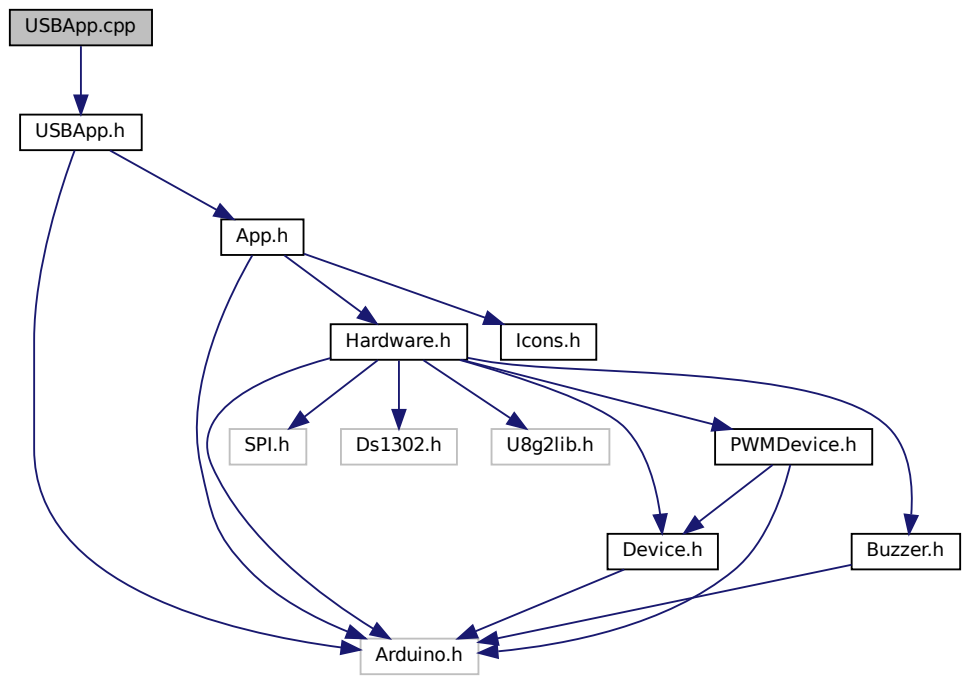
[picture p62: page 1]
USBApp.cpp; USBApp.h; Arduino.h; App.h; Hardware.h; Icons.h; SPI.h; U8g2lib.h; Device.h; PWMDevice.h; Buzzer.h

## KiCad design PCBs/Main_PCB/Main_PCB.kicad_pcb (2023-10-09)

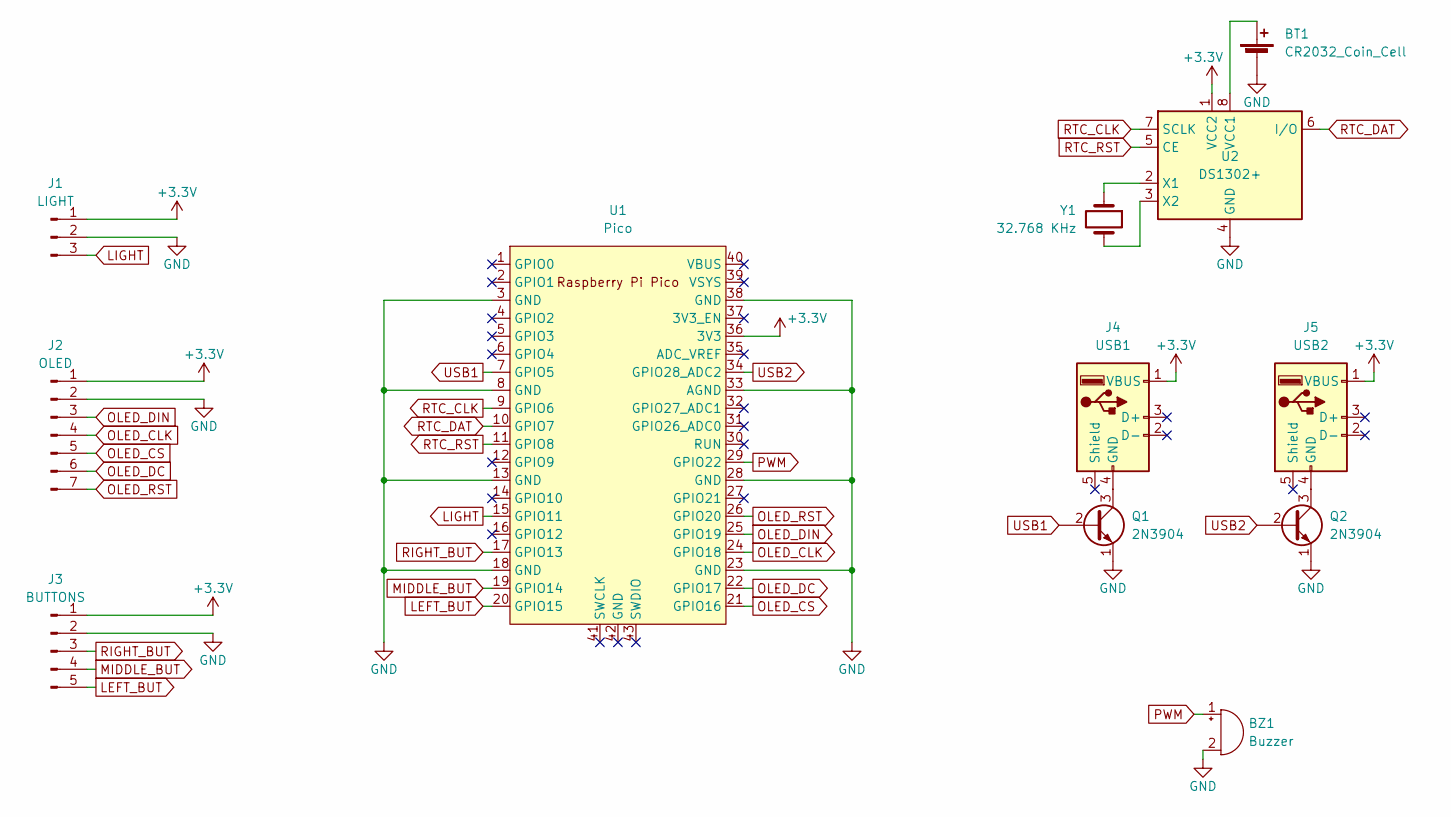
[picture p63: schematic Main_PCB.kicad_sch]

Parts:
BT1: CR2032_Coin_Cell; Vertical_CR2032_Battery_Holder
BZ1: Buzzer; MagneticBuzzer_ProSignal_ABT-410-RC
J1: LIGHT; PinHeader_1x03_P2.54mm_Vertical
J2: OLED; PinHeader_1x07_P2.54mm_Vertical
J3: BUTTONS; PinHeader_1x05_P2.54mm_Vertical
J4: USB1; USB_A_CONNFLY_DS1095-WNR0
J5: USB2; USB_A_CONNFLY_DS1095-WNR0
Q1, Q2: 2N3904; TO-92_Inline
U1: Pico; RPi_Pico_SMD_TH
U2: DS1302+; DIP-8_W7.62mm
Y1: 32.768 KHz; Crystal_DS26_D2.0mm_L6.0mm_Horizontal

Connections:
+3.3V: J1.1, J2.1, J3.1, J4.1 (VBUS), J5.1 (VBUS), U1.36 (3V3), U2.1 (VCC2)
GND: BT1.2 (-), BZ1.2 (+), J1.2, J2.2, J3.2, Q1.1 (E), Q2.1 (E), U1.3 (GND), U1.8 (GND), U1.13 (GND), U1.18 (GND), U1.23 (GND), U1.28 (GND), U1.33 (AGND), U1.38 (GND), U2.4 (GND)
LEFT_BUT: J3.5, U1.20 (GPIO15)
LIGHT: J1.3, U1.15 (GPIO11)
MIDDLE_BUT: J3.4, U1.19 (GPIO14)
unnamed: BT1.1 (+), U2.8 (VCC1)
unnamed: J4.4 (GND), Q1.3 (C)
unnamed: J5.4 (GND), Q2.3 (C)
unnamed: U2.2 (X1), Y1.1
unnamed: U2.3 (X2), Y1.2
OLED_CLK: J2.4, U1.24 (GPIO18)
OLED_CS: J2.5, U1.21 (GPIO16)
OLED_DC: J2.6, U1.22 (GPIO17)
OLED_DIN: J2.3, U1.25 (GPIO19)
OLED_RST: J2.7, U1.26 (GPIO20)
PWM: BZ1.1 (-), U1.29 (GPIO22)
RIGHT_BUT: J3.3, U1.17 (GPIO13)
RTC_CLK: U1.9 (GPIO6), U2.7 (SCLK)
RTC_DAT: U1.10 (GPIO7), U2.6 (I/O)
RTC_RST: U1.11 (GPIO8), U2.5 (CE)
USB1: Q1.2 (B), U1.7 (GPIO5)
USB2: Q2.2 (B), U1.34 (GPIO28_ADC2)

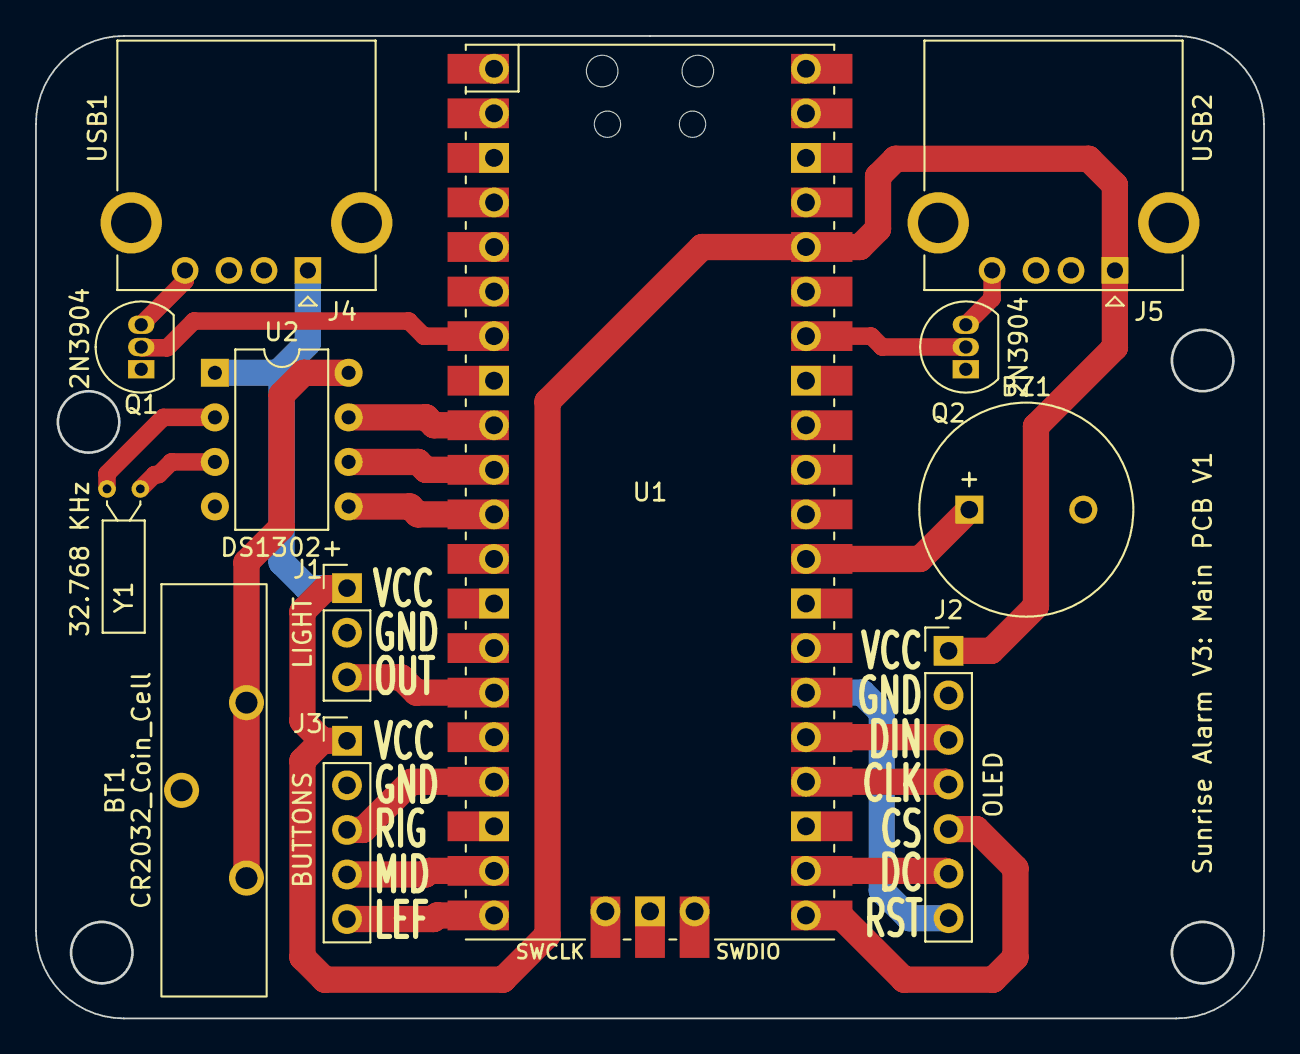
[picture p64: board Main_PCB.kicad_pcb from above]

Board: 2 copper layers, 70.0 x 56.0 mm, 12 parts (0 on the bottom side), 22 nets.

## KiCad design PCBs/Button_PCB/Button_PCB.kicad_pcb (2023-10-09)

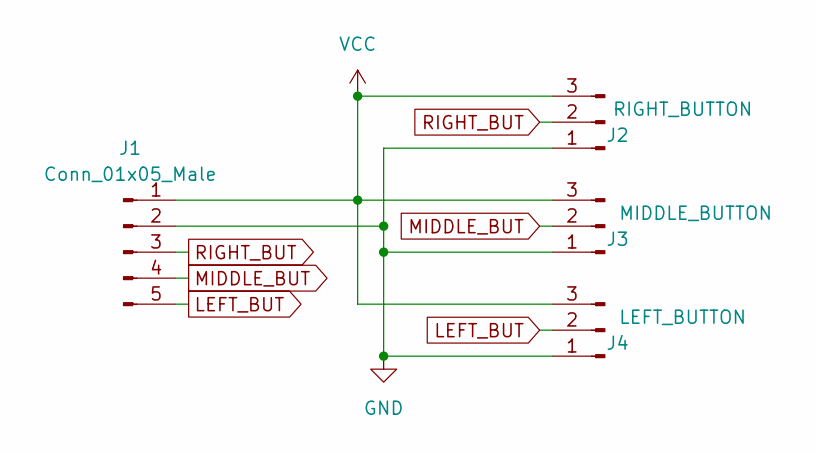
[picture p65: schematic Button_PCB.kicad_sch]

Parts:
J1: Conn_01x05_Male; PinHeader_1x05_P2.54mm_Vertical
J2: RIGHT_BUTTON; TTP223
J3: MIDDLE_BUTTON; TTP223
J4: LEFT_BUTTON; TTP223

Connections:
GND: J1.2, J2.1, J3.1, J4.1
LEFT_BUT: J1.5, J4.2
MIDDLE_BUT: J1.4, J3.2
RIGHT_BUT: J1.3, J2.2
VCC: J1.1, J2.3, J3.3, J4.3

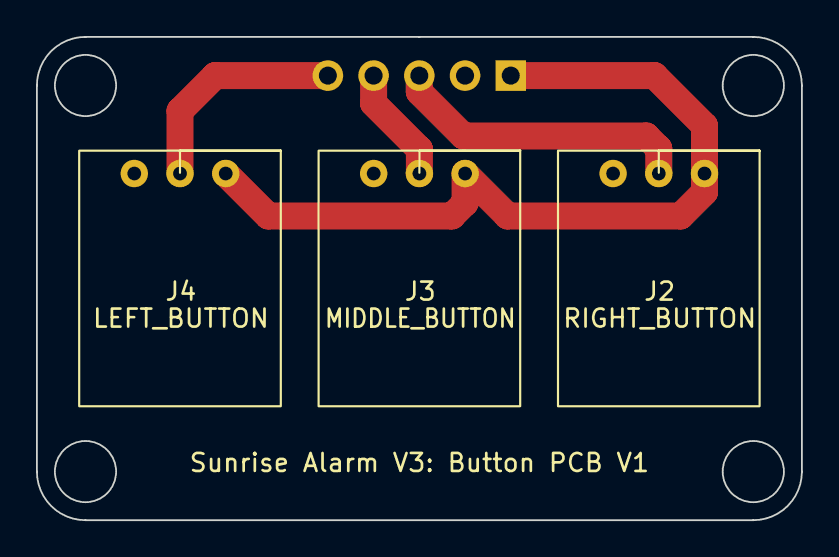
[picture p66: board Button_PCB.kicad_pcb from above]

Board: 2 copper layers, 42.5 x 26.8 mm, 4 parts (1 on the bottom side), 5 nets.

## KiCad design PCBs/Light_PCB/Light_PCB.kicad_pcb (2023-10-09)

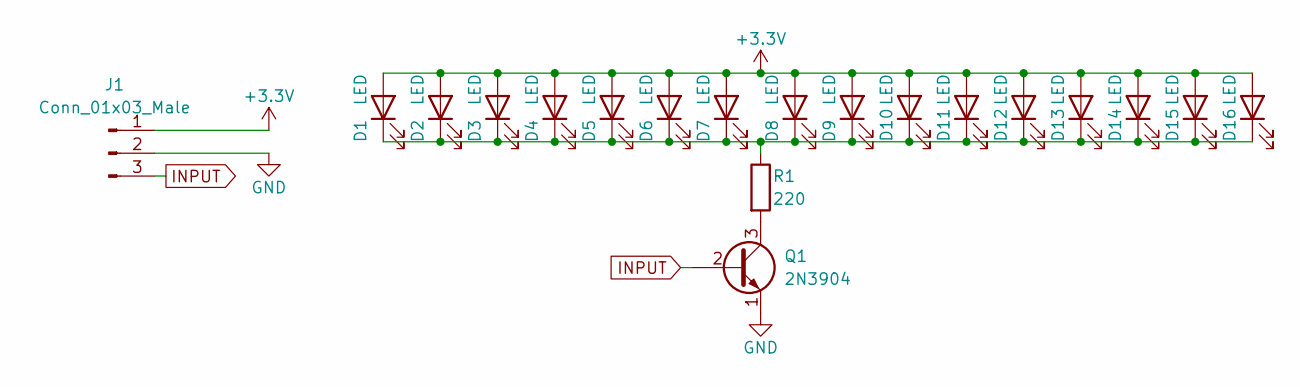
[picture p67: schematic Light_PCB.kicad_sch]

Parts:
D1, D2, D3, D4, D5, D6, D7, D8, D9, D10, D11, D12, D13, D14, D15, D16: LED; LED_0805_2012Metric_Pad1.15x1.40mm_HandSolder
J1: Conn_01x03_Male; PinSocket_1x03_P2.54mm_Vertical
Q1: 2N3904; TO-92_Inline
R1: 220; R_0805_2012Metric_Pad1.20x1.40mm_HandSolder

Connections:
+3.3V: D1.2 (A), D2.2 (A), D3.2 (A), D4.2 (A), D5.2 (A), D6.2 (A), D7.2 (A), D8.2 (A), D9.2 (A), D10.2 (A), D11.2 (A), D12.2 (A), D13.2 (A), D14.2 (A), D15.2 (A), D16.2 (A), J1.1
GND: J1.2, Q1.1 (E)
INPUT: J1.3, Q1.2 (B)
unnamed: D1.1 (K), D2.1 (K), D3.1 (K), D4.1 (K), D5.1 (K), D6.1 (K), D7.1 (K), D8.1 (K), D9.1 (K), D10.1 (K), D11.1 (K), D12.1 (K), D13.1 (K), D14.1 (K), D15.1 (K), D16.1 (K), R1.1
unnamed: Q1.3 (C), R1.2

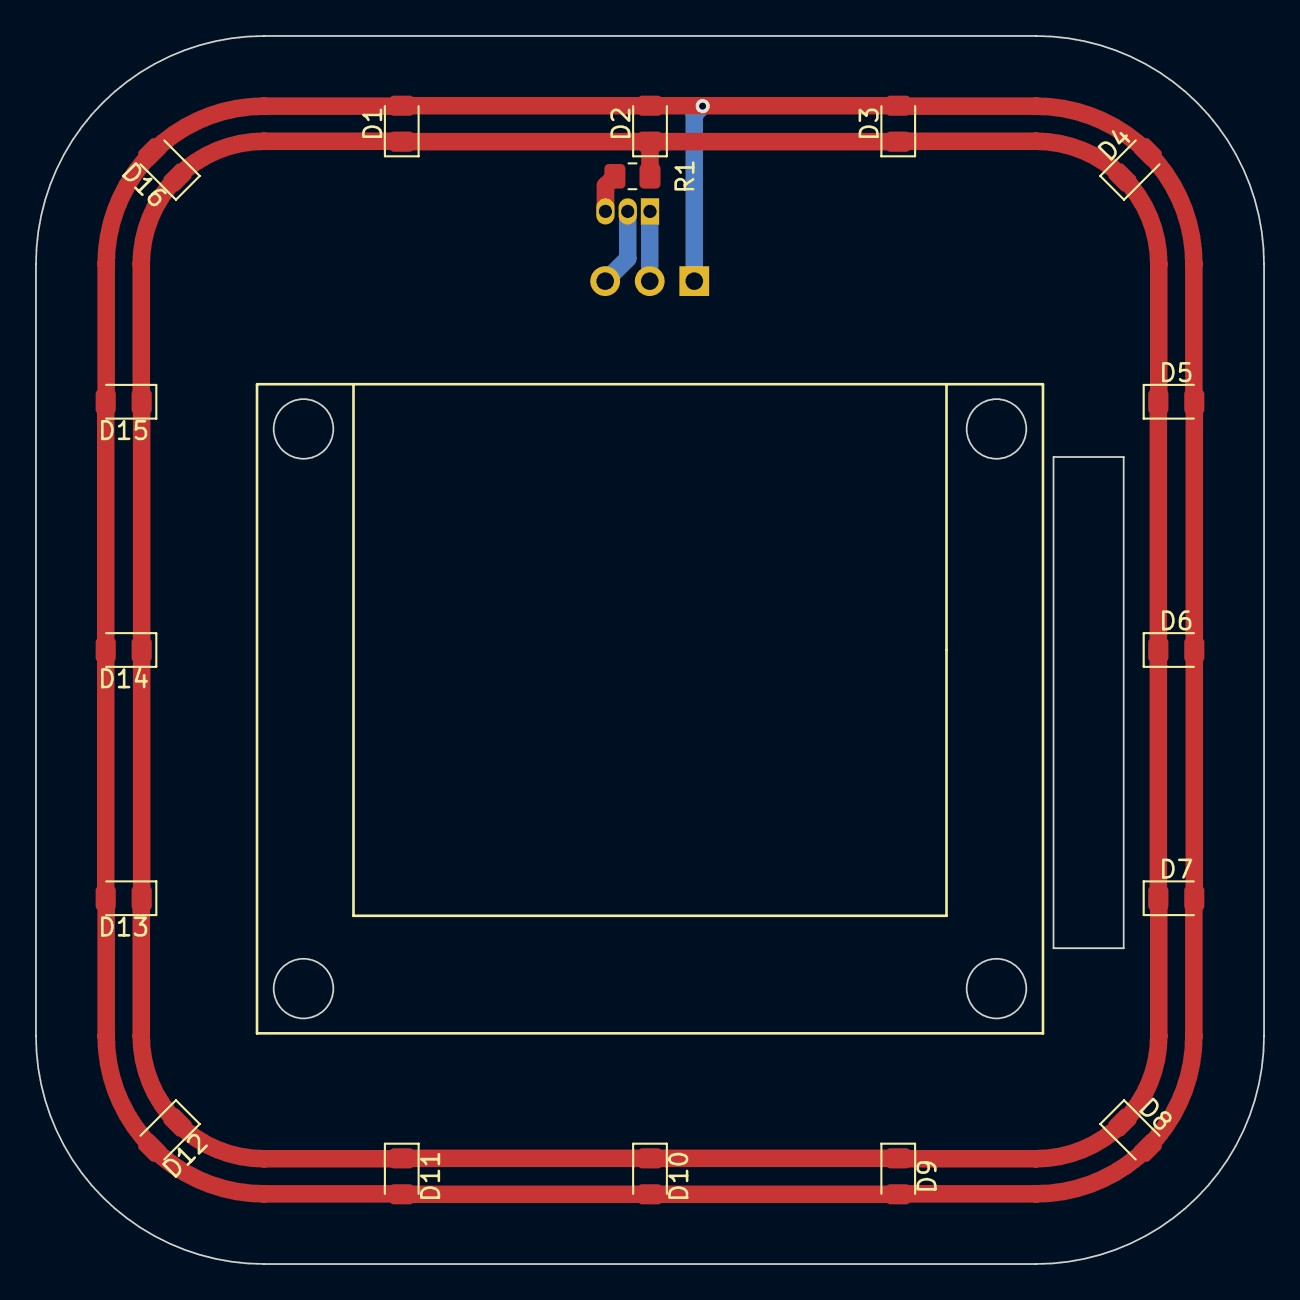
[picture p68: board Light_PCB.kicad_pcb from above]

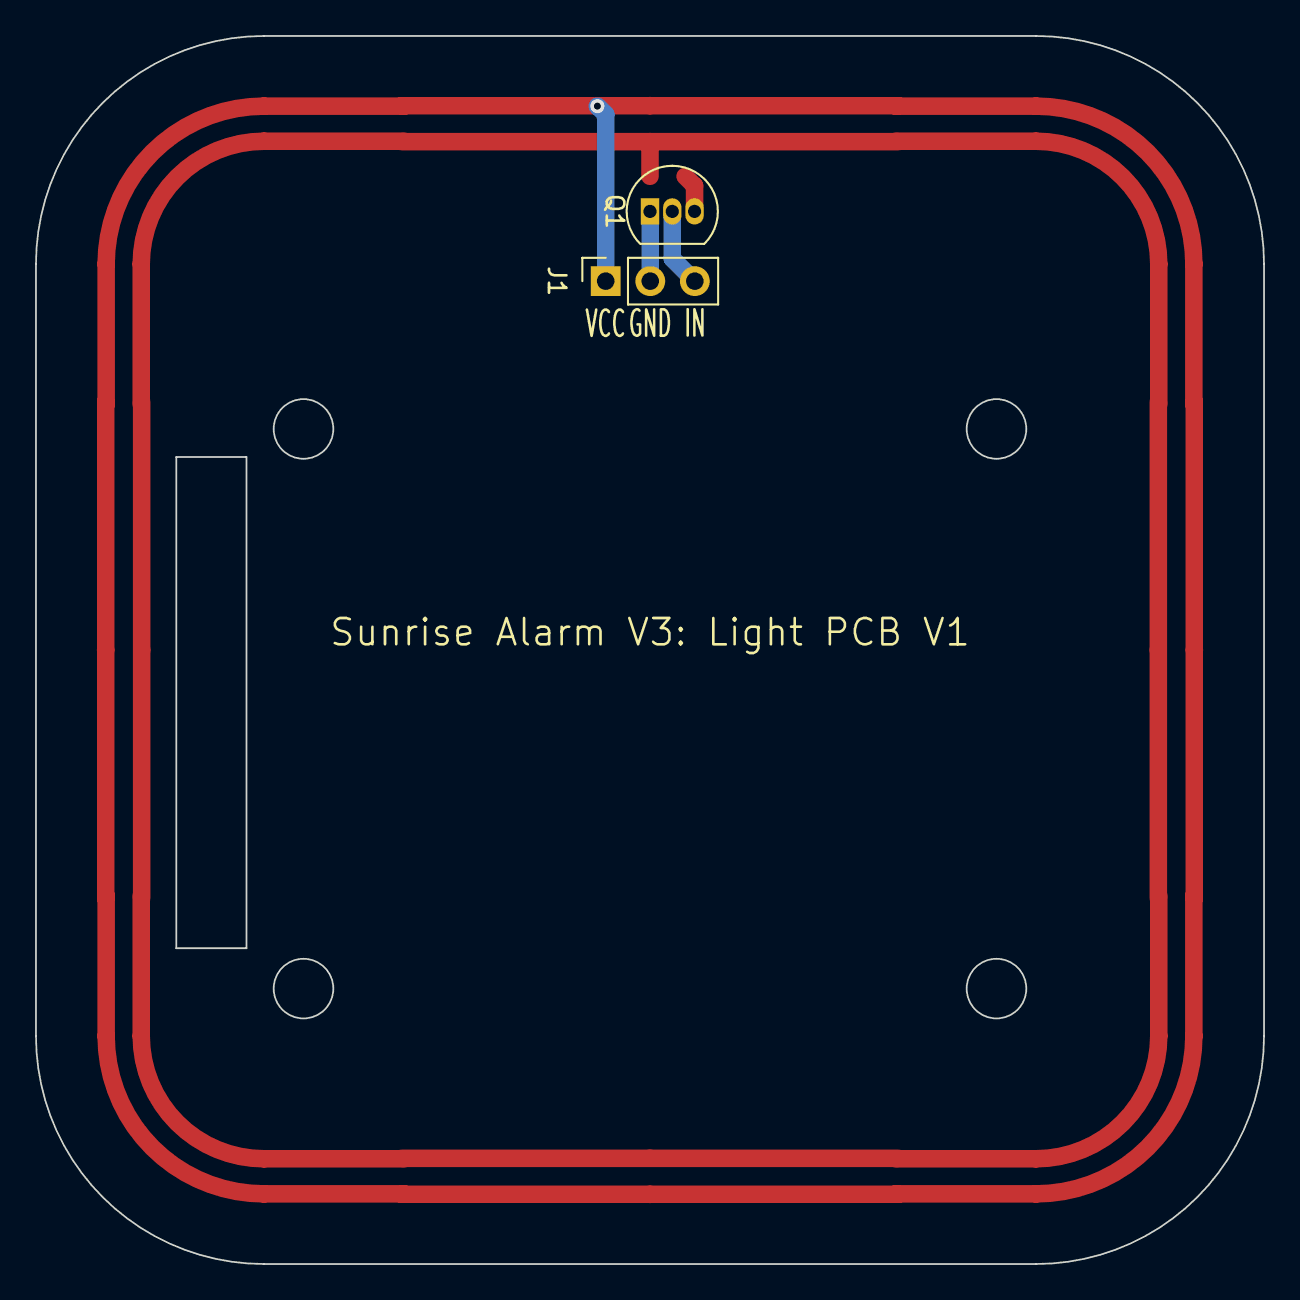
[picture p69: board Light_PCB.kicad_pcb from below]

Board: 2 copper layers, 70.0 x 70.0 mm, 19 parts (2 on the bottom side), 5 nets.

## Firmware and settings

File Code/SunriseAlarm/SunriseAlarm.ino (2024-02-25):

/**
 * @file SunriseAlarm.ino
 * @author Sean Price
 * @brief Software to run on the Sunrise Alarm V3
 * @version 0.1
 * @date 13/01/2024
 * 
 * The goal with this software is to make it modular and easy to add functionality in the form of "Apps". 
 * This will make it possible to add new features, without breaking existing functionality.
 */


// ---------------------------------------- D E F I N E   P I N   N U M B E R S ----------------------------------------
#define LEFT_BUTTON 15
#define MIDDLE_BUTTON 14
#define RIGHT_BUTTON 13

#define LIGHT 11
#define USB_1 5
#define USB_2 28

#define BUZZER 22

#define RTC_RESET 8
#define RTC_CLK 6
#define RTC_DATA 7

#define SCREEN_WIDTH 128
#define SCREEN_HEIGHT 128
#define SCREEN_CLK 18
#define SCREEN_DATA 19
#define SCREEN_CS 16
#define SCREEN_DC 17
#define SCREEN_RESET 20


// --------------------------------------------------- I N C L U D E ---------------------------------------------------
#include <SPI.h>
#include <Ds1302.h>
#include <U8g2lib.h>

#include "Device.h"
#include "PWMDevice.h"
#include "Buzzer.h"
#include "Hardware.h"

#include "App.h"
#include "LightApp.h"
#include "AlarmApp.h"
#include "USBApp.h"  


// -------------------------------------- I N S T A N T I A T E   H A R D W A R E --------------------------------------

U8G2_SSD1327_WS_128X128_F_4W_SW_SPI display(U8G2_R0, SCREEN_CLK, SCREEN_DATA, SCREEN_CS, SCREEN_DC, SCREEN_RESET);

Ds1302 rtc(RTC_RESET, RTC_CLK, RTC_DATA);

PWMDevice light(LIGHT, 4);
Device usb1(USB_1);
Device usb2(USB_2);

Buzzer buzzer(BUZZER);

struct Hardware hw = {display, rtc, light, usb1, usb2, buzzer};  // Put all hardware component in a struct for portabilty


// ---------------------------------- I N S T A N T I A T E   A P P L I C A T I O N S ----------------------------------

AlarmApp alarmApp(hw);
LightApp lightApp(hw);
USBApp usbApp(hw);

const int noOfApps = 3;
App* apps[noOfApps];

uint8_t currentApp = 0;


// ------------------------------------------------- V A R I A B L E S -------------------------------------------------
volatile bool leftPressed = false;
volatile bool middlePressed = false;
volatile bool rightPressed = false;

uint8_t screenTimeoutStart = 22;      // Sets when the screen timeout period begins
uint8_t screenTimeoutEnd = 7;         // Sets when the screen timeout period ends
uint8_t lastTimeoutMin = 0;           // Stores the minute when the device was last woken during the timeout period
uint8_t lastTimeoutSec = 0;           // Stores the second when the device was last woken during the timeout period
bool screenOn = true;                 // Shows whether the screen should currently be on or off

Ds1302::DateTime now;                 // DateTime struct to store the current time


// ----------------------------------------------------- S E T U P -----------------------------------------------------
void setup() 
{
  // Setup Buttons
  pinMode(LEFT_BUTTON, INPUT_PULLUP);
  pinMode(MIDDLE_BUTTON, INPUT_PULLUP);
  pinMode(RIGHT_BUTTON, INPUT_PULLUP);
  
  attachInterrupt(digitalPinToInterrupt(LEFT_BUTTON), leftISR, RISING);
  attachInterrupt(digitalPinToInterrupt(MIDDLE_BUTTON), middleISR, RISING);
  attachInterrupt(digitalPinToInterrupt(RIGHT_BUTTON), rightISR, RISING);

  // Initialise Objects
  rtc.init();
  display.begin();

  // Setup Apps
  apps[0] = &alarmApp;
  apps[1] = &lightApp;
  apps[2] = &usbApp;

  // Run App Initialisations
  for(int i = 0; i < noOfApps; i++)
  {
    apps[i]->init(); 
  }
}

// ------------------------------------------------------ M A I N ------------------------------------------------------
void loop() 
{
  if(millis() % 1000 == 0)                    // Update the time and display every second
  {
    hw.rtc.getDateTime(&now);  
    
    if(screenOn)
    {
      updateDisplay();
    }    
  }
  
  
  if(anyButtonPressed())                      // Handle any button presses (when they occur)
  {
    if(duringTimeoutPeriod())                 // If the button press occurred during the screen timeout period
    {
      screenOn = true;                        // Turn on the screen 

      lastTimeoutMin = now.minute;            // and update the variables so that the screen turns off after 1 minute    
      lastTimeoutSec = now.second;  
    }
    
    if(buzzer.isSounding())                   // If the alarm is currently sounding, any button will turn it off
    {
      alarmApp.openApp();                     // Turn off the alarm
      updateDisplay();                        // Update the display to turn off the bell icon

      delay(2000);                            // Wait to prevent extra button presses affecting the program

      leftPressed = false;                    // Cancel any extra button presses
      middlePressed = false;
      rightPressed = false;
    }
    else if(apps[currentApp]->isOpen())       // If an app is open, forward the button presses to the app
    {
      if(leftPressed)
      {
        apps[currentApp]->leftAction();
        leftPressed = false;
      }
      if(middlePressed)
      {
        apps[currentApp]->middleAction();
        middlePressed = false;
      }
      if(rightPressed)
      {
        apps[currentApp]->rightAction();
        rightPressed = false;
      }
    }
    else                                      // When in the menu
    {
      if(leftPressed)                         // Left button presses move to the previous app
      {
        display.clearBuffer();
        display.clearDisplay();

        if(currentApp == 0)
        {
          currentApp = noOfApps - 1;
        }
        else
        {
          currentApp--;
        }

        leftPressed = false;
      }
      
      if(middlePressed)                       // Middle button presses open the current app
      {
        apps[currentApp]->openApp();
        middlePressed = false;
      }
      
      if(rightPressed)                        // Right button presses move to the next app
      {
        display.clearBuffer();
        display.clearDisplay();

        currentApp++;
        if(currentApp >= noOfApps)
        {
          currentApp = 0;
        }
        rightPressed = false;
      }
    }

    updateDisplay();
  }

  
  for(int i = 0; i < noOfApps; i++)           // Run App Background Tasks
  {
    apps[i]->backgroundTasks(); 
  }

  if(dueToTimeoutScreen())                    // Turn off the screen when it is due to timeout
  {
    screenOn = false;

    display.clearBuffer();
    display.clearDisplay();
  }

  if(endOfTimeoutPeriod())                    // At the end of the timeout period
  {
    lastTimeoutMin = 0;                       // Reset the timeout
    lastTimeoutSec = 0;  

    screenOn = true;                          // Turn the display back on
  }
}


// -------------------------------------------- U P D A T E   D I S P L A Y --------------------------------------------
void updateDisplay()
{
  if(apps[currentApp]->isOpen())
  {
    apps[currentApp]->display();
  }
  else
  {
    apps[currentApp]->displayMenuPage();
  }
}


// ---------------------------------------- A N Y   B U T T O N   P R E S S E D ----------------------------------------
bool anyButtonPressed()
{
  return (leftPressed || middlePressed || rightPressed);
}


// ------------------------------------- D U E   T O   T I M E O U T   S C R E E N -------------------------------------
bool dueToTimeoutScreen()
{
  // True if within the timeout period, 1 minute has passed since the last button press and the screen is currently on
  return duringTimeoutPeriod() && ((now.minute == lastTimeoutMin + 1) && (now.second == lastTimeoutSec) && screenOn);
}


// ------------------------------------- D U R I N G   T I M E O U T   P E R I O D -------------------------------------
bool duringTimeoutPeriod()
{
  return ((now.hour >= screenTimeoutStart && now.hour <= 23) || (now.hour >= 0 && now.hour < screenTimeoutEnd));
}


// ------------------------------------- E N D   O F   T I M E O U T   P E R I O D -------------------------------------
bool endOfTimeoutPeriod()
{
  return (now.hour == screenTimeoutEnd && now.minute == 0 && now.second == 0);
}


// -------------------------------------------- L E F T   I N T E R R U P T --------------------------------------------
void leftISR() 
{
  leftPressed = true;
}

// ------------------------------------------ M I D D L E   I N T E R R U P T ------------------------------------------
void middleISR() 
{ 
  middlePressed = true;
}

// ------------------------------------------- R I G H T   I N T E R R U P T -------------------------------------------
void rightISR() 
{
  rightPressed = true;
}

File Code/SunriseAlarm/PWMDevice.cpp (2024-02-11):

/**
 * @file PWMDevice.cpp
 * @author Sean Price
 * @brief Implements the PWMDevice class.
 * @version 0.1
 * @date 13/01/2024
 * 
 * 
 */

#include "PWMDevice.h"

const uint8_t PWMDevice::DEFAULT_MAX_LEVEL = 4;
const uint8_t PWMDevice::DEFAULT_LEVEL = DEFAULT_MAX_LEVEL;
const uint8_t PWMDevice::MIN_VAL = 10;
const uint8_t PWMDevice::MAX_VAL = 255;


//--------------------------------------------------- C O N S T R U C T O R S ---------------------------------------------------
PWMDevice::PWMDevice(uint8_t pinNo) : Device(pinNo), pinNo(pinNo), level(DEFAULT_LEVEL), maxLevel(DEFAULT_MAX_LEVEL) {}

PWMDevice::PWMDevice(uint8_t pinNo, uint8_t maxLevel) : Device(pinNo), pinNo(pinNo), level(DEFAULT_LEVEL), maxLevel(maxLevel) {}


//-------------------------------------------------------- T U R N   O N --------------------------------------------------------
void PWMDevice::turnOn()
{
  Device::turnOn();

  uint8_t value = MIN_VAL + ((MAX_VAL-MIN_VAL)/maxLevel)*level;

  analogWrite(pinNo, value);
}


//--------------------------------------------------- T U R N   O N   F U L L ---------------------------------------------------
void PWMDevice::turnOnFull()
{
  Device::turnOn();
}


//------------------------------------------------- I N C R E A S E   L E V E L -------------------------------------------------
void PWMDevice::increaseLevel()
{
  if(level < maxLevel)
  {
    level++;
  }
}


//------------------------------------------------- D E C R E A S E   L E V E L -------------------------------------------------
void PWMDevice::decreaseLevel()
{
  if(level > 0)
  {
    level--;
  }
}


//------------------------------------------------------ G E T   L E V E L ------------------------------------------------------
uint8_t PWMDevice::getLevel()
{
  return level;
}

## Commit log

2023-09-08 V3.1.0-alpha Captured Main PCB Schematic
    [Main_PCB.kicad_pcb, Main_PCB.kicad_sch]
2023-09-08 V3.2.0-alpha Designed Main PCB
    [Main_PCB.kicad_pcb, Main_PCB.kicad_sch]
2023-09-08 V3.3.0-alpha Designed Light PCB
    [Light_PCB.kicad_pcb, Light_PCB.kicad_sch]
2023-09-08 V3.4.0-alpha Designed Button PCB
    [Button_PCB.kicad_pcb, Button_PCB.kicad_sch]
2023-09-09 V3.4.1-alpha Added PCB Labels
    [Light_PCB.kicad_pcb, Main_PCB.kicad_pcb]
2023-09-23 V3.4.2-alpha Changed Buzzer Footprint
    [Main_PCB.kicad_pcb, Main_PCB.kicad_sch]
2023-10-09 V3.4.3-alpha Generated PCB Gerber Files
    [Button_PCB-B_Cu.gbr, Button_PCB-B_Mask.gbr, Button_PCB-B_Paste.gbr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]
2023-10-15 V3.5.0-alpha Designed Enclosure
    [Button_PCB.f3d, Main_PCB.f3d, OLED.f3d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]
2023-11-10 V3.5.1-alpha Manufactured Enclosure
    [Acrylic_Lasercutting.dxf, Sunrise_Alarm_V3_Enclosure_Printable.stl]
2023-11-10 V3.6.0-alpha Soldered PCBs
2024-01-13 V3.8.0-alpha Started Writing the SunriseAlarm Code
    - Set up interrupts for the three navigation buttons
    - Defined and implemented the Device class
    - Defined and implemented the Buzzer class
    - Started Doxygen documentation
    [SunriseAlarm.ino]
2024-01-14 V3.10.0-alpha Implemented Basic Alarm Application - Changed App function names (backgroundFunctions -> backgroundTasks) and (displayMenuIcon -> displayMenuPage) - Defined and implemented the AlarmApp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
    [SunriseAlarm.ino]
2024-01-21 V3.11.1-alpha Implemented Light Dimming - Defined and implemented the PWMDevice class to add PWM functionality to the Device class. - Changed the light to be a PWMDevice rather than a Device. - Added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
2024-02-11 V3.11.2-alpha Implemented LightApp backgroundTasks - Added maxLevel to the PWMDevice constructor. - Added the PWMDevice::getLevel() function. - Added the PWMDevice::turnOnFull() function. - Implement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
2024-02-25 V3.12.3-alpha Allowed Any Button to Turn Alarm Off
